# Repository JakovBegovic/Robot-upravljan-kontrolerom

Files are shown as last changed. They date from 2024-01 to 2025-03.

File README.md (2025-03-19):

Razvijeno s kolegama Vinkom Bohnecom, Mateom Zovićem, Antoniom Bernobićem. <br>
Izvorni kod, dokumentacija i video prikaz projekta za kolegij Programiranje ugrađenih sustava. Sadrži kod za 2 mikrokontrolera - odašiljač WiFi signala i primatelj WiFi signala. Projekt razvijen u PlatformIO ekstenziji za Visual Studio Code. Kod je razvijen za Dasduino CONNECTPLUS mikrokontrolere.<br>
Iz projekta dobiveni svi bodovi. Kao posljedica projekta dobivena [pisana preporuka](https://github.com/JakovBegovic/Robot-upravljan-kontrolerom/blob/caef50e12dc3403a5f9ce1389835898fd6788e6c/Pismo%20preporuke%20za%20Jakova%20Begovi%C4%87a.pdf) dr. Borisa Tomaša.
<br><br>
Mapa [3D-modeli](https://github.com/JakovBegovic/Robot-upravljan-kontrolerom/tree/2fcbab7a2e5f61b7f1df8ae97a9870575ed1f150/3D-modeli) sadrži .stl datoteke. One predstavljaju gornji i donji dio kućišta daljinskog upravljača.
<br><br>
Za videozapis koji prikazuje kako robot funkcionira me kontaktirajte.
<br><br>
Shield: [][cc-by-nc-sa]

This work is licensed under a
[Creative Commons Attribution-NonCommercial-ShareAlike 4.0 International License][cc-by-nc-sa].

[][cc-by-nc-sa]

[cc-by-nc-sa]: http://creativecommons.org/licenses/by-nc-sa/4.0/
[cc-by-nc-sa-image]: https://licensebuttons.net/l/by-nc-sa/4.0/88x31.png
[cc-by-nc-sa-shield]: https://img.shields.io/badge/License-CC%20BY--NC--SA%204.0-lightgrey.svg

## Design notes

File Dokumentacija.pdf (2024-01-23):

SVEUČILIŠTE U ZAGREBU

FAKULTET ORGANIZACIJE I INFORMATIKE

V A R A Ž D I N

Vinko Bohnec, Antonio Bernobić,

Mateo Zović, Jakov Begović

Studij: Informacijski i poslovni sustavi

# ROBOT UPRAVLJAN KONTROLEROM

PROJEKT

Mentor/Mentorica:

mag. inf. Lovro Posarić

Varaždin, siječanj 2023.

i

Vinko Bohnec, Antonio Bernobić,

Mateo Zović, Jakov Begović

Izjava o izvornosti

Izjavljujemo da je naš projekt izvorni rezultat našeg rada te da se u izradi istoga nismo

koristili drugim izvorima osim onima koji su u njemu navedeni. Za izradu rada su korištene

etički prikladne i prihvatljive metode i tehnike rada.

ii

Sažetak

Projekt se bavi izradom robota kojim je moguće upravljati preko vlastito izrađenog

kontrolera (daljinskog upravljača). Robot omogućuje razne mogućnosti i funkcionalnosti, od

kojih su neke, upravljanje kretanjem robota, paljenje i gašenje led svjetla u definiranim

intervalima, puštanje raznih zvučnih signala i melodija putem zujalice te automatsko

kočenje. Temelj projekta jesu dvije Dasduino pločice koje međusobno komuniciraju i

razmjenjuju podatke. Jedna od njih služi kao kontroler za slanje naredbi, dok druga

Dasduino pločica obavlja definirane radnje. Projekt ne iziskuje samo trud oko slaganja

robota i spajanja dijelova, već se bazira i na kvalitetnom programskom rješenju. Svaka

Dasduino pločica ima zaseban program koji izvršava svake sekunde. Ovaj projekt

predstavlja savršen spoj mehanike (dijelovi robota), elektronike (elektroničke komponente)

i informatike (programiranja), koji u konačnici tvore robota.

Ključne riječi: robot, daljinsko upravljanje, kretanje, Dasduino pločice, komunikacija

programsko rješenje, mehanika, elektronika, informatika

iii

## Sadržaj

## 1. Uvod

U današnjem svijetu sve više i više je prisutno raznih robota. Svi smo se, već sigurno

bar jednom, susreli s pojmom robota, no što je zapravo robot i kako on djeluje? „Robot je

automatizirani stroj višestruke namjene, koji može obavljati neke zadaće slične ljudskom

djelovanju. S obzirom na stupanj autonomnosti, mogućnosti interakcije s okolinom i

inteligencije, razlikuje se nekoliko skupina (generacija) robota.“ [1] Prvoj skupini pripadaju

programirani roboti, u drugu skupinu spadaju roboti opremljeni nizom senzora, a trećoj skupini

robota pripadaju inteligentni roboti. „Programirani roboti ne koriste povratnu informaciju o

svojem stvarnom stanju i ne mogu korigirati pogrješke vođenja. Roboti druge generacije

opremljeni su nizom senzora, koje koriste za dobivanje povratnih informacija o svojem

stvarnom stanju i stanju okoline. Inteligentni roboti imaju sposobnost učenja, rezoniranja i

donošenja zaključaka.“ [1] S obzirom na brzi razvoj robota, kojem trenutno najviše pridonosi

ubrzani razvoj umjetne inteligencije, nije ni čudo da su danas roboti prisutni u mnogim

djelatnostima. Shodno tome, roboti imaju različite primjene, od industrijskih i kućanskih robota,

pa sve do svemirskih i humanoidnih robota. Iz svega navedenog je na posljetku, i tema našeg

projekta proizašla iz ideje i želje za izradom vlastitog robota. Izrada robota nije jednostavna jer

ona uključuje složeni sustav koji objedinjuje računalnu opremu i komponente te programsku

podršku to jest izvršni program. Upravo robot i njegove komponente predstavljaju pojam

ugrađenog sustava, a njegovim izvršnim programom se ostvaruje ideja programiranja za

ugrađene sustave. Iz tog razloga, robot upravljan vlastoručno izrađenim kontrolerom

predstavlja savršenu temu za stjecanje novih znanja i vještina iz područja ne samo robotike,

već i iz čitavog područja ugrađenih sustava.

## 2. Modeli

Model u tehničkom svijetu predstavlja pojednostavljenu stvarnost. Dakle, prema nekim

predmetima iz stvarnosti moguće je izraditi (najčešće) manju, pojednostavljenu repliku tog

predmeta. Izradom modela se nastoji omogućiti promatranje kompleksnog sustava i njegovih

ključnih dijelova. U ovome slučaju, model robota je prikazan na način da se dijelovi robota prvo

promatraju kao samostalna cjelina, a tek kasnije kao složena cjelina, to jest složeni sustav.

## 2.1. Općenita arhitektura sustava

Osnovna konstrukcija robota sastoji se od postolja robota, četiri kotača, četiri

istosmjerna (DC) motora, te vijaka i matica. Takva konstrukcija tvori temelj za daljnji razvoj

robota. Na osnovnu konstrukciju su nadalje dodani razni elektronički dijelovi potrebni za

ispravno funkcioniranje robota. Ti dijelovi će biti predstavljeni pojedinačno u sljedećim

poglavljima.

Slika 1: Osnovna konstrukcija robota - Dijelovi

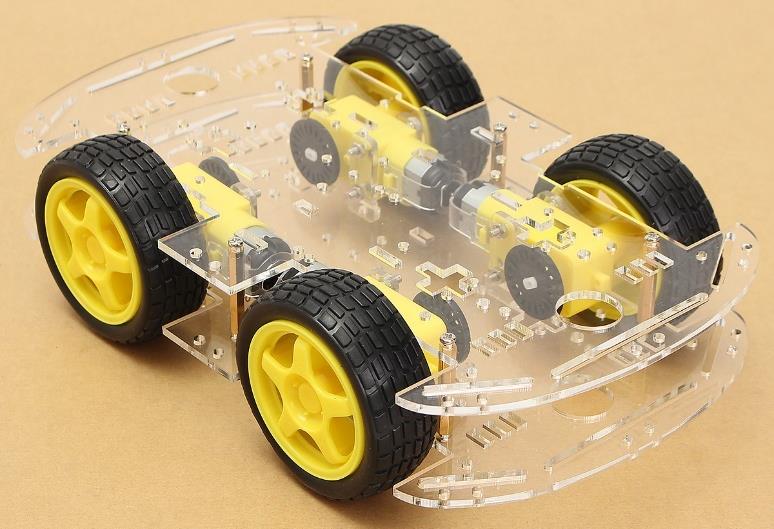
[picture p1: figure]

Slika 2: osnovna konstrukcija robota - Sastavljeno

Slika 1: osnovna konstrukcija robota - Dijelovi

### 2.1.1.Dasduino CONNECTPLUS (ESP32)

Dasduino CONNECTPLUS pločica je elektronička pločica razvijena od hrvatske

kompanije Soldered Electronics. Soldered Electronics nalazi se u Osijeku, a bavi se razvojem,

dizajniranjem te proizvodnjom vlastitih elektroničkih proizvoda. Jedan od njihovih proizvoda

jest Dasduino pločica. Postoje različite vrste pločica Dasduina, koje se razlikuju po čipu koji

koriste i elektroničkoj shemi. U sljedećem dijelu će biti opisana pločica korištena u ovome radu

- Dasduino CONNECTPLUS (ESP32).

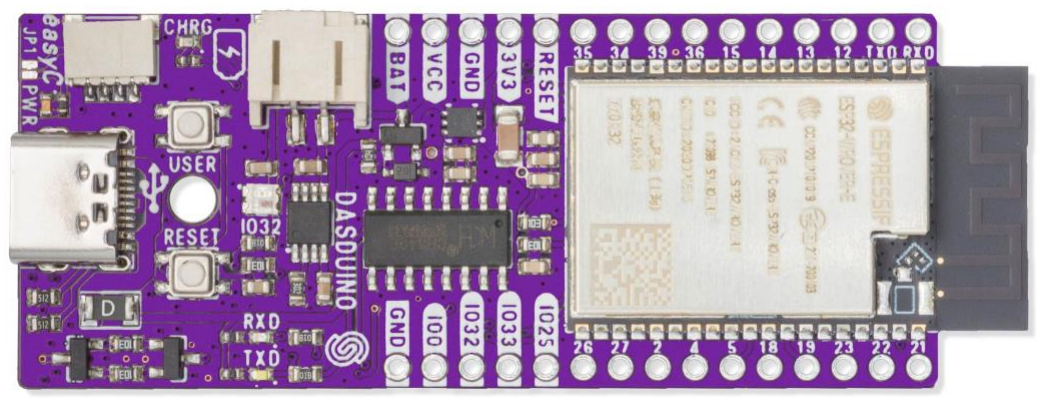
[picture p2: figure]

Dasuino CONNECTPLUS pločica koristi mikročip ESP32-WROVER-E, te koristi napon

rada 3.3V (integrirani 5V regulator). Pločica se sastoji od 30 pinova, od kojih neki rade s

digitalnim signalima, analognim te onih pinova koji imaju mogućnost upravljanja širinom

(duljinom) impulsa (PWM). Na sljedećoj slici [Slika 4] je prikazana Dasduino CONNECTPLUS

pločica skupa sa svojima konekcijama.

Slika 3: Dasduino CONNECT PLUS

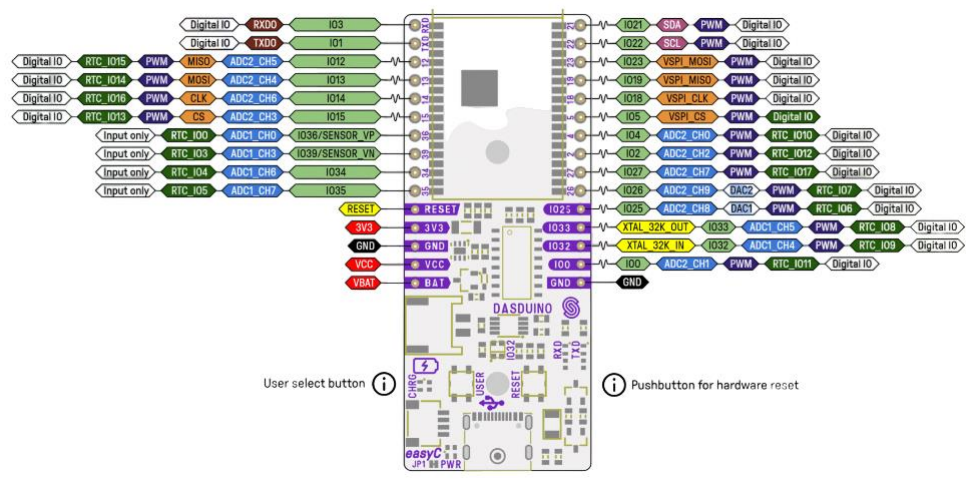
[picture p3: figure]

Na prikazu konekcija se može uočiti da većina pinova sadrži opciju upravljanja širinom

impulsa (PWM – Pulse Width Modulation), a samim time, ti pinovi se mogu koristiti za rad s

analognim signalima. Skoro svi pinovi omogućavaju rad s ulaznim i izlaznim signalima (IO –

Input Output).

### 2.1.2. Modul za upravljanje motorima - L298N DC motor driver

Za upravljanje motorima robota nije dovoljna samo Dasduino pločica, već je potreban i

upravljač motora, koji je u ovom slučaju to L298N DC motor driver. Na taj način se preko

Dasduino pločice šalju naredbe upravljaču motora o promjenama brzine i smjeru vrtnje motora.

Slika 4: Dasduino CONNECTPLUS (ESP32) - Prikaz konekcija

Slika 5: L298N DC motor driver

Promjena brzine vrtnje motora se ostvaruje promjenom ulaznog napona na motorima.

Taj princip rada se zasniva na promjeni širine impulsa (PWM – Pulse Width Modulation) tako

što slanjem duljih impulsa dajemo veću brzinu vrtnje motora, a slanjem manjih odnosno kraćih

impulsa dajemo manju brzinu vrtnje motora, što je vidljivo na sljedećoj slici [Slika 6].

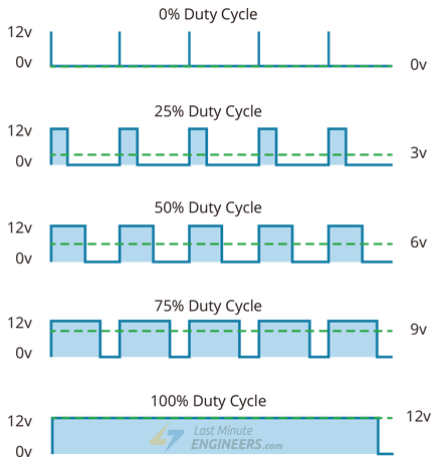
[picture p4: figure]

Promjena smjera vrtnje motora se ostvaruje promjenom polariteta ulaznog napona, a

takav način rada zasnovan je na principu H-Bridge. H označava izgled strujnog kruga u kojem

imamo 4 sklopke od koje su dvije sklopke zatvorene, dok su druge dvije otvorene. Time

mijenjamo polaritet napona na motorima. Bridge, što u prijevodu označava most, isto

predstavlja izgled i način rada strujnog kruga, čiji je princip rada prikazan na sljedećoj slici

[Slika 7].

Slika 6: promjenom širine impulsa dobiva se različiti napon na izlazu

Slika 7: mijenjanje polariteta napona na motorima H-Bridge principom

Kod L298N DC motor drivera L298N predstavlja naziv čipa koji koristi, koji je srce toga

modula. DC (Direct Current) označava da taj modul koristi istosmjernu struju, a motor driver

opisuje funkciju modula – upravljanje motorima. Pomoću L298N DC motor drivera možemo

upravljati dvama istosmjernim motorima istovremeno, koji se napajaju od 5 do 35 V. Njih

spajamo na izlaze 1,2,3 i 4 (OUT1, 2 ,3, i 4). Pomoću ENA i ENB upravljamo brzinama vrtnje

motora, a ulazima 1,2,3 i 4 (IN1, 2, 3, i 4) upravljamo smjerom vrtnje motora. VCC je napajanje,

koje služi za pogon motora, a može biti između 5 i 35 V (preporuča se između 7 i 12 V). GND

označava minus gdje se strujni krug zatvara. Za ispravan rad modula, potrebno je dovesti 5 V

na pin 5V kako bi modul radio.

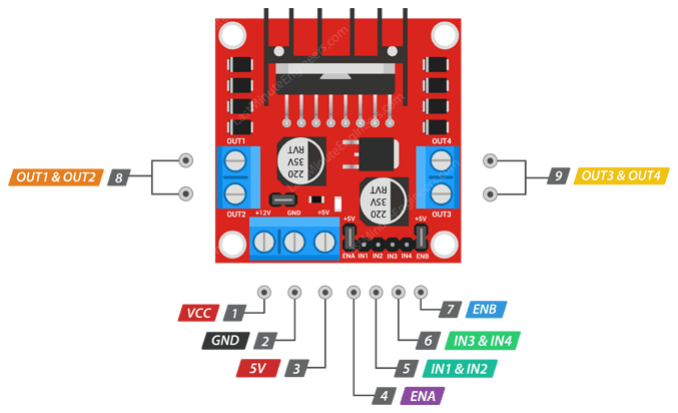
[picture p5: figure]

### 2.1.3. Senzor udaljenosti – HC-SR04 Ultrasonic Sensor

Senzor udaljenosti ili ultrazvučni senzor je senzor za mjerenje udaljenosti pomoću

ultrazvučnih valova. Glava senzora emitira ultrazvučni val koji se odbija od nekog predmeta ili

objekta te se nazad vraća do glave senzora. Ultrazvučni senzor mjeri udaljenost objekta

mjerenjem vremena između emisije i prijema, odnosno između slanja i primanja signala. Za

ispravan rad senzora udaljenosti potrebno je pravilno spojiti četiri pina samog senzora. Vcc pin

služi za napajanje senzora, a najčešće je to 5 V. Trigger pin se koristi za slanje signala, dok

se Echo pin koristi za primanje signala. Ground pin se, kao i obično, spaja na minus to jest

uzemljenje, a služi za zatvaranje strujnog kruga. Izgled senzora udaljenosti i njegovih pinova

prikazan je na sljedećoj slici [Slika 9].

Slika 8: L298N DC motor driver – Prikaz pinova

HC-SR04 ultrazvučni senzor udaljenosti, u teoriji, može izmjeriti udaljenost između 2

cm i 450 cm, dok je praksi ta udaljenost puno manja – od 2 cm do 80 cm. Senzor računa

udaljenost s preciznošću od 3 mm. Za izračun udaljenosti između objekta i senzora koristi se

formula:

L =

1
2

∗ T ∗ C

gdje L predstavlja udaljenost, T vrijeme proteklo između slanja i primanja signala, te C koji

predstavlja brzinu zvuka. Umnožak se množi s

1
2

kako bi se dobila vrijednost udaljenosti za

jedan smjer (a ne za oba). Vrijednost koja se uzima za brzinu zvuka je 330m/s.

Slika 9: HC-SR04 Ultrasonic Sensor - Prikaz pinova

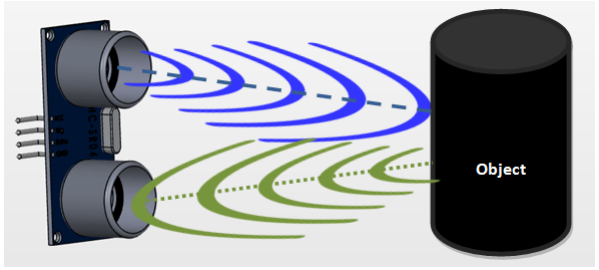
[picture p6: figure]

Slika 10: princip rada ultrazvučnog senzora

### 2.1.4. Zujalica

Zujalice su elektronički elementi predviđeni za generiranje zvuka. Postoje dvije vrste

zujalica – aktivna i pasivna zujalica. Aktivna zujalica ima u sebi ugrađen oscilatorski krug, te ju

je dovoljno spojiti na izvor napajanja i ona će proizvoditi zvuk određene frekvencije. Kod

zujalice bez oscilatorskog kruga, to jest kod pasivne zujalice, potrebno je dovesti oscilirajući

signal kako bi proizvela zvuk. Oscilirajući signal jednostavno je postići jer se programiranjem

može odrediti početak i kraj generiranja zvuka, odnosno tona. Aktivna i pasivna zujalica se

mogu razlikovati tako što aktivna zujalica ima crno dno, dok pasivna ima dno zelene boje.

Njihovo spajanje se izvodi na način da se + (plus) zujalice spaja na neki od digitalnih pinova

na Dasduino pločici, dok se – (minus) zujalice spaja na GND.

### 2.1.5. Svjetleće diode

Naziv LED dolazi iz engleskog jezika i kratica je za Light Emitting Diode, što bi u

prijevodu značilo dioda koja emitira svjetlost. Hrvatski naziv je svjetleća dioda, međutim u

praksi se najčešće koristi izraz LE-dioda. LE-dioda ima dvije nožice od kojih je jedna duža, dok

je druga kraća. Duža nožica se zove anoda i spaja se na + (plus), a kraća nožica, to jest

katoda, spaja se na – (minus). Osim po duljini nožice, anodu je moguće prepoznati jer je u

kućištu presjek (zarez) dviju nožica bliži anodi, odnosno površina katode u kućištu je veća od

površine anode. Kako bi LE-dioda zasvijetlila potrebno ju je priključiti na napon od oko 2 V.

Dakle, anoda se spaja na digitalni pin, dok se katoda spaja na GND. Međutim, svaki digitalni

pin daje 5 V, zbog čega je potrebno dodati otpornik od 330 Ω u strujni krug kako LE-dioda ne

bi pregorjela.

Slika 11: zujalice - Aktivna zujalica (lijevo) i Pasivna zujalica (desno)

Slika 12: svjetleća dioda - Prepoznavanje anode i katode

### 2.1.6. Maska odašiljača

U svrhu uljepšavanja i unaprjeđenja našeg proizvoda, koristili smo 3D printer kako bi

isprintali masku za odašiljač radio signala. U svrhu toga koristili smo alat Fusion 360.

Na slici gore moguće je vidjeti donji dio maske. On sadrži držač za bateriju i logo „GoranTM“. Držač za bateriju napravljen je za bateriju koja će napajati odašiljač. Nakon

printanja otvor je bio pre uzak te smo stoga trebali koristiti brusilicu kako bi ga proširili za oko

pola milimetra. Nepreciznost 3D printera dovela je do užeg otvora nego očekivano.

Slika 13: donji dio maske

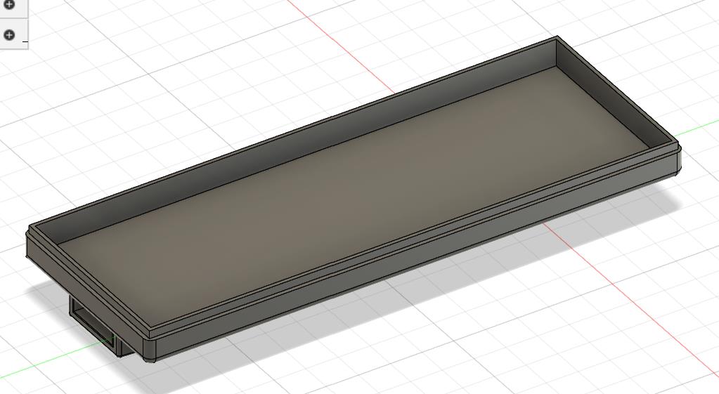
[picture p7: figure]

Slika 14: ptičja perspektiva na donji dio maske

Uz to, ovaj donji dio poklopca ima uvlaku na samom rubu, kao što je prikazano na slici

gore. Svrha tome je da se spoji sa gornjim dijelom maske bez korištenja ljepila. Na taj način

se baterija može izmijeniti nakon što se potroši. Tolerancija između uvlake gornjeg i donjeg

dijela maske je ukupno 0,1 mm.

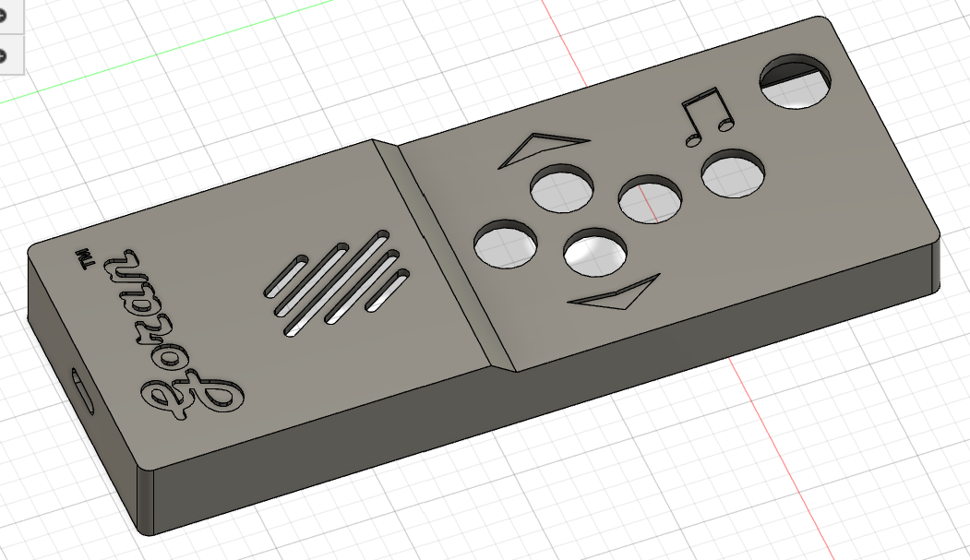
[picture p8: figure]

Gornji dio maske sadrži prostor za 5 gumba, rupu za zujalicu, uzdužene rupe za

hlađenje mikroupravljača, rupu za USB-C konektor, rupu za spajanje baterije na

mikroupravljač, sugestivne reljefe vezane uz funkcionalnosti gumbova i logo projekta.

Gumbovi na odašiljaču imaju toleranciju od oko 2 mm od rupa koje su za njih izrađene.

Slika 15: mravlja perspektiva na gornji dio maske

Slika 16: ptičja perspektiva na gornji dio maske

## 2.2. Složena arhitektura sustava

Elektroničke komponente navedene u prošlim poglavljima, ovdje čine jednu zajedničku

cjelinu, odnosno predstavljaju složeni sustav robota. Kako točno robot funkcionira, razmjenjuje

podatke i prima naredbe biti će razrađeno u ostalim poglavljima, dok je cilj ovog poglavlja

vizualno prikazati izgled robota. Shema spajanja će također biti predstavljena kasnije.

Slijedeće slike [Slika 17], [Slika 18] služe za lakše razumijevanje poglavlja koja slijede, pritom

pružajući čitatelju jasnu sliku o predmetu promatranja.

Slika 17: Prikaz složenog robota

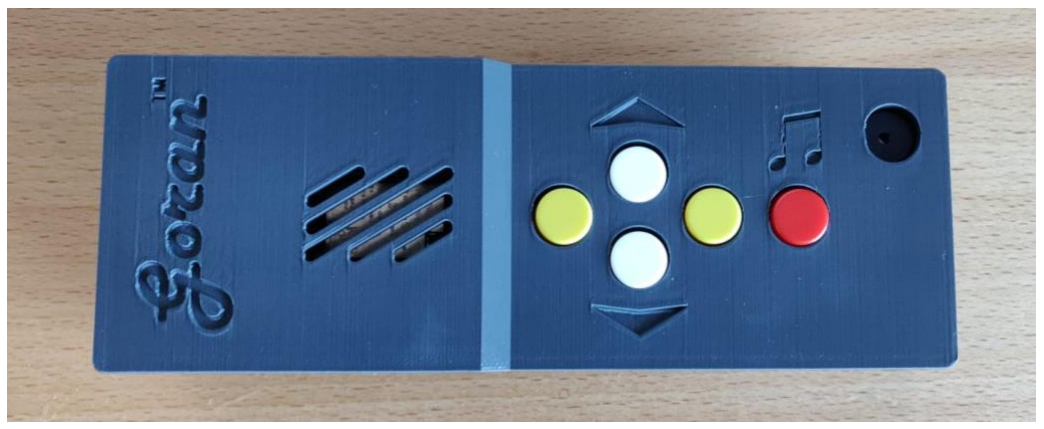
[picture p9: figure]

Slika 18: Prikaz daljinskog kontrolera (odašiljača)

## 2.3. Komunikacijski dijagrami

Prema [5] komunikacijski dijagram je tip UML dijagrama koji prikazuje interakciju

između objekata, dijelova ili podsistema. Isključujući temporalnu komponentu, on daje iste

informacije kao dijagram slijeda.

U sljedećih par dijagrama odnosit ću ne na gumbove „gore“, „dolje“, „lijevo“, „desno“ i

„muzika“. To su 4 gumba nađena na odašiljaču. Kada se on usmjeri tako da su gumbovi bliži

desnoj ruci, tada je vidljiv njihov točan poredak. Gumb „muzika“ je prepoznatljiv po silueti dvaju

povezanih nota na kućištu odašiljača.

### 2.3.1. Korisnik ne pritišće niti jedan gumb

Na slici gore možete vidjeti kako komponente ovog robota međusobno komuniciraju u

slučaju da korisnik ne pritišće niti jedan gumb. Mikrokontroler RF auta, kao i mikrokontroler

odašiljača su tipa ESP32. To znači da sadrže dvije procesorske jedinice – CPU0 i CPU1. [6]

CPU0 je zaslužan za procesiranje mrežnih zadataka, kao što je komuniciranje putem WiFi ili

Bluetooth tehnologije. CPU1 je zaslužan za izvršavanje ostalog koda, kao što je upravljanje

motorima i paljenje i gašenje LED-ica.

Poruka 2 predstavlja slanje paketa koji sadrži naredbu sa odašiljača na robot auto. U

slučaju kada korisnik ne pritišće niti jedan gumb naredba koja se šalje je cijeli broj 0. Taj se

Slika 19: dijagram komunikacije kada korisnik ne pritišće niti jedan gumb paket šalje sa CPU0 na odašiljaču na CPU0 na primatelju. Poruka 3. predstavlja dodjeljivanje

procesorskog vremena objektu tipa MusicPlayer.

Poruka 4 i 5 predstavlja prijepis vrijednosti primljene naredbe u varijablu dijeljenu

između CPU0 i CPU1 kod robot auta. OnDataRecv() je zapravo funkcija pozvana nakon

primanja paketa.

Poruke 6, 7, 8, 9 i 10 se odnose na dodjeljivanje objektima ultrasonicControlForward,

ultrasonicControlForward, rightBlinker, leftBlinker i backwardsBuzzer procesorsko vrijeme.

Svrha toga je održavanje pravilnog vremena treptanja LED-ica, pravog vremena i duljine

sviranja nota na zujalici, provjeravanje udaljenosti prednjeg i stražnjeg branika robot auta od

drugih objekata.

U slučaju kada se niti jedan gumb ne pritišće naredba kojom se upravljaju motori je

Stop(). Ona se šalje motorima koji upravljaju kotačima robota. To je vidljivo putem poruke 11.

Poruke 12 i 13 se odnose na gašenje LED-ica. Naime, one bi trebale biti upaljene samo

kada robot auto skreće lijevo ili desno.

Poruka 14 daje informaciju je li upaljena zujalica koja signalizira vožnju u natrag. Ako

je, treba ju ugasiti. To se radi pomoću naredbe 15.

### 2.3.2. Korisnik pritišće gumb gore

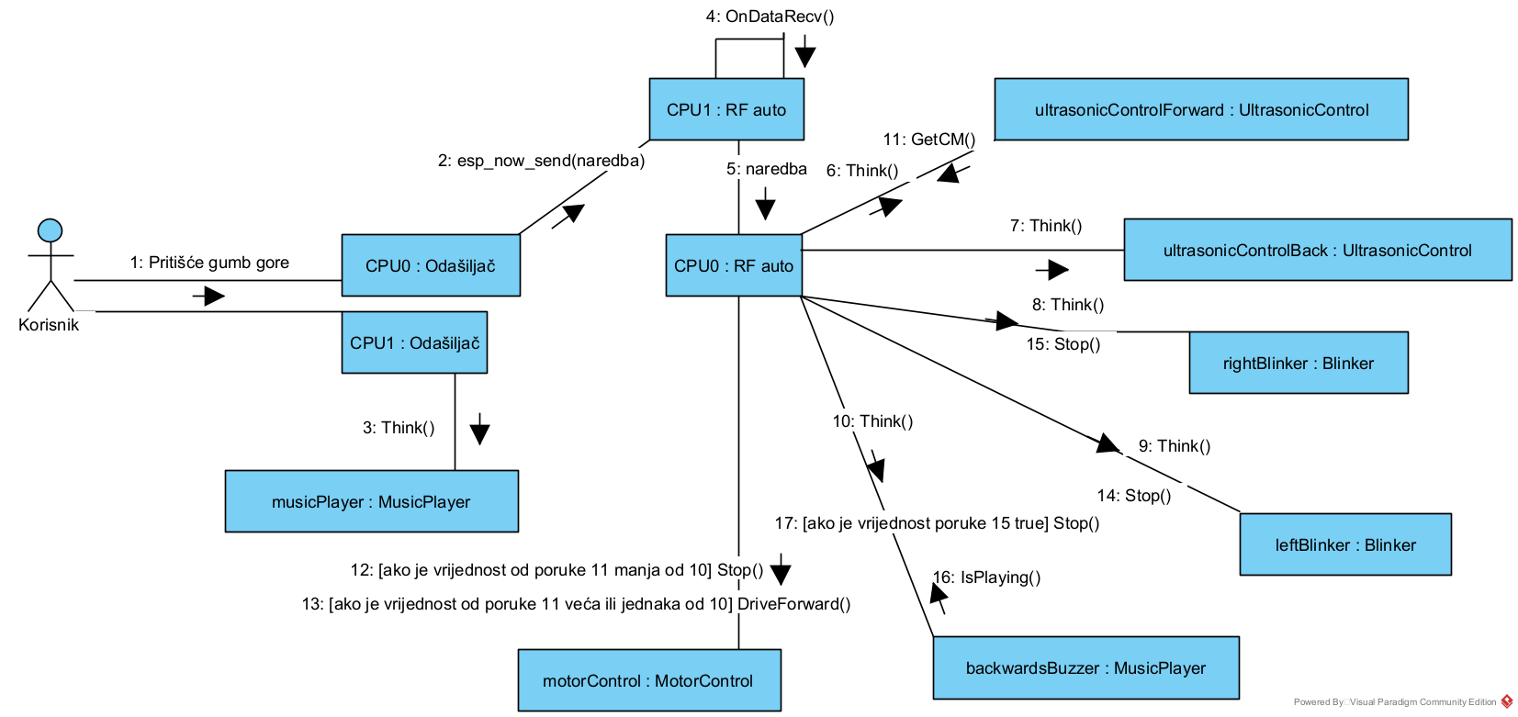
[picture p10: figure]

Slika 20: dijagram komunikacije kada korisnik pritišće gumb gore

Na slici gore možete vidjeti kako komponente ovog robota međusobno komuniciraju u

slučaju da korisnik pritišće gumb gore. Poruke 1, 2, 3, 4, 5, 6, 7, 8, 9, 10 su iste kao i na

prošlom dijagramu.

Svrha poruke 11 je prikupljanje informacije koliko je prednji branik robot auta udaljen

od sljedećeg objekta. Ta vrijednost je zatim korištena u porukama 12 i 13 gdje se njihova

pojava bazira na toj vrijednosti. Vrijednost 10 predstavlja 1 centimetara od sljedećeg objekta.

To je udaljenost na kojoj bi robot auto trebao blokirati vožnju dalje.

Poruke 14 i 15 identične su porukama 12 i 13 na prošlom dijagramu. Poruke 16 i 17

identične su porukama 14 i 15 na prošlom dijagramu.

### 2.3.3. Korisnik pritišće gumb dolje

Na slici gore možete vidjeti kako komponente ovog robota međusobno komuniciraju u

slučaju da korisnik pritišće gumb dolje. Poruke 1, 2, 3, 4, 5, 6, 7, 8, 9, 10 su iste kao i na

prošlom dijagramu.

Svrha poruke 11 je prikupljanje informacije koliko je prednji branik robot auta udaljen

od sljedećeg objekta. Ta vrijednost je zatim korištena u porukama 12 i 13 gdje se njihova

pojava bazira na toj vrijednosti. Vrijednost 10 predstavlja 1 centimetara od sljedećeg objekta.

To je udaljenost na kojoj bi robot auto trebao blokirati vožnju dalje.

Poruke 14 i 15 identične su porukama 12 i 13 na prošlom dijagramu. Poruke 16 i 17

identične su porukama 14 i 15 na prošlom dijagramu.

Slika 21: dijagram komunikacije kada korisnik pritišće gumb dolje

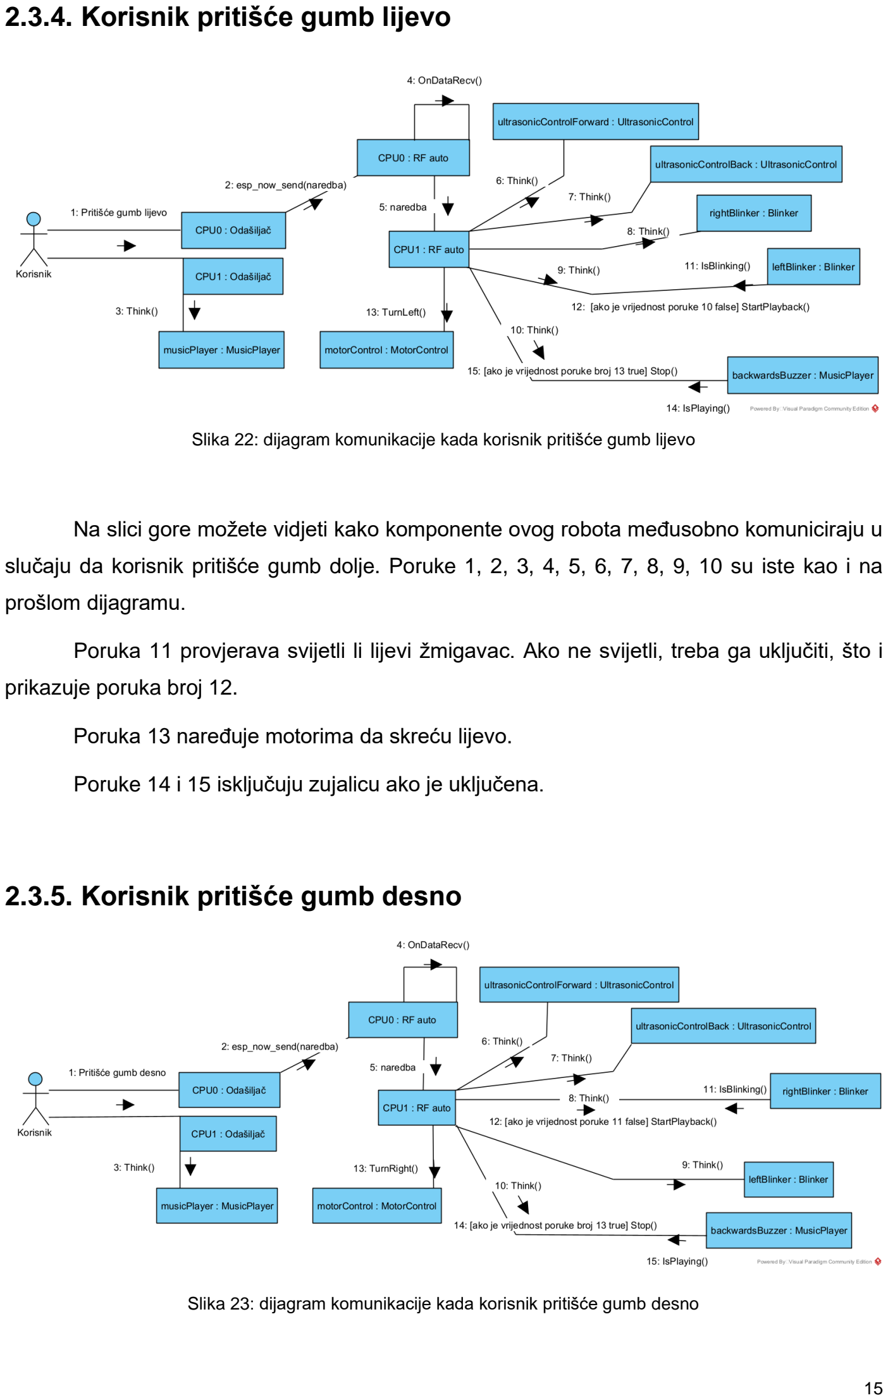
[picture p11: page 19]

### 2.3.4. Korisnik pritišće gumb lijevo

Na slici gore možete vidjeti kako komponente ovog robota međusobno komuniciraju u

slučaju da korisnik pritišće gumb dolje. Poruke 1, 2, 3, 4, 5, 6, 7, 8, 9, 10 su iste kao i na

prošlom dijagramu.

Poruka 11 provjerava svijetli li lijevi žmigavac. Ako ne svijetli, treba ga uključiti, što i

prikazuje poruka broj 12.

Poruka 13 naređuje motorima da skreću lijevo.

Poruke 14 i 15 isključuju zujalicu ako je uključena.

### 2.3.5. Korisnik pritišće gumb desno

Slika 23: dijagram komunikacije kada korisnik pritišće gumb desno

Slika 22: dijagram komunikacije kada korisnik pritišće gumb lijevo

Na slici gore možete vidjeti kako komponente ovog robota međusobno komuniciraju u

slučaju da korisnik pritišće gumb desno. Poruke 1, 2, 3, 4, 5, 6, 7, 8, 9, 10 su iste kao i na

prošlom dijagramu.

Poruka 11 provjerava svijetli li desni žmigavac. Ako ne svijetli, treba ga uključiti, što i

prikazuje poruka broj 12.

Poruka 13 naređuje motorima da skreću desno.

Poruke 14 i 15 isključuju zujalicu ako je uključena.

### 2.3.6. Korisnik pritisne gumb muzika

Na slici gore možete vidjeti kako komponente ovog robota međusobno komuniciraju u

slučaju da korisnik pritisne gumb muzika. Nakon pritiska gumba se pozove prekid u obliku

funkcije musicButtonInterrupt(). Svrha tog prekida je postavljanje zastavice za prijelaz na

sljedeću pjesmu. U sebi ima sadržan tzv. switch debouncing sa odgodom detekcije od 200

milisekundi. Korak 3 izvršava se neovisno o tom pritisku – u svakom slučaju. Zbog pritiska

gumba muzika aktivira se korak 4. Tada se objektu musicPlayer pošalje naredba

StartPlayback() koja završi sa izvađanjem trenutne i krene sa izvađanjem sljedeće pjesme.

Poruka broj 5 je pozivanje metode Think() unutar same klase. Svrha toga je

dodjeljivanje procesorskog vremena toj klasi.

Slika 24: dijagram kada korisnik pritišće gumb muzika

## 2.4. Dijagram aktivnosti

Prema [7] dijagrami aktivnosti opisuju kako su aktivnosti koordinirane. To prikazuje na

različitim razinama apstrakcije. Kako bi izgradili model aktivnosti koristili smo notaciju BPMN.

Ona pruža puno više mogućnosti u smislu definiranja vrste prekida, vrste događaja, vrste

grananja i slično.

Cijeli dijagram je podijeljen na 3 staze: stazu korisnik, stazu upravljača-odašiljača i

stazu prijemnika-robota.

### 2.4.1. Staza korisnika

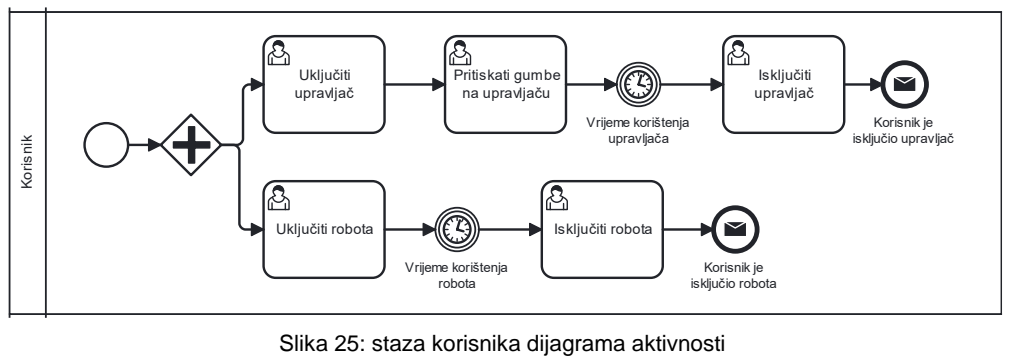
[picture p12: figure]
Korisnik; Uključiti robota; Uključiti upravljač; Pritiskati gumbe na upravljaču; Isključiti upravljač; Isključiti robota; Vrijeme korištenja robota; Korisnik je isključio robota; Korisnik je isključio upravljač; Vrijeme korištenja upravljača

Aktivnosti korisnika se dijele na dva slijeda – slijed uključivanja upravljača i slijed

uključivanja robota. Nakon što korisnik izvede aktivnost uključivanja robota on njime upravlja.

Nakon što je gotov isključuje upravljač. To šalje poruku u stazu upravljača.

Nakon što prođe neko vrijeme kroz koje korisnik koristi robota on ga isključuje i šalje

se poruka stazi robota.

Slika 25: staza korisnika dijagrama aktivnosti

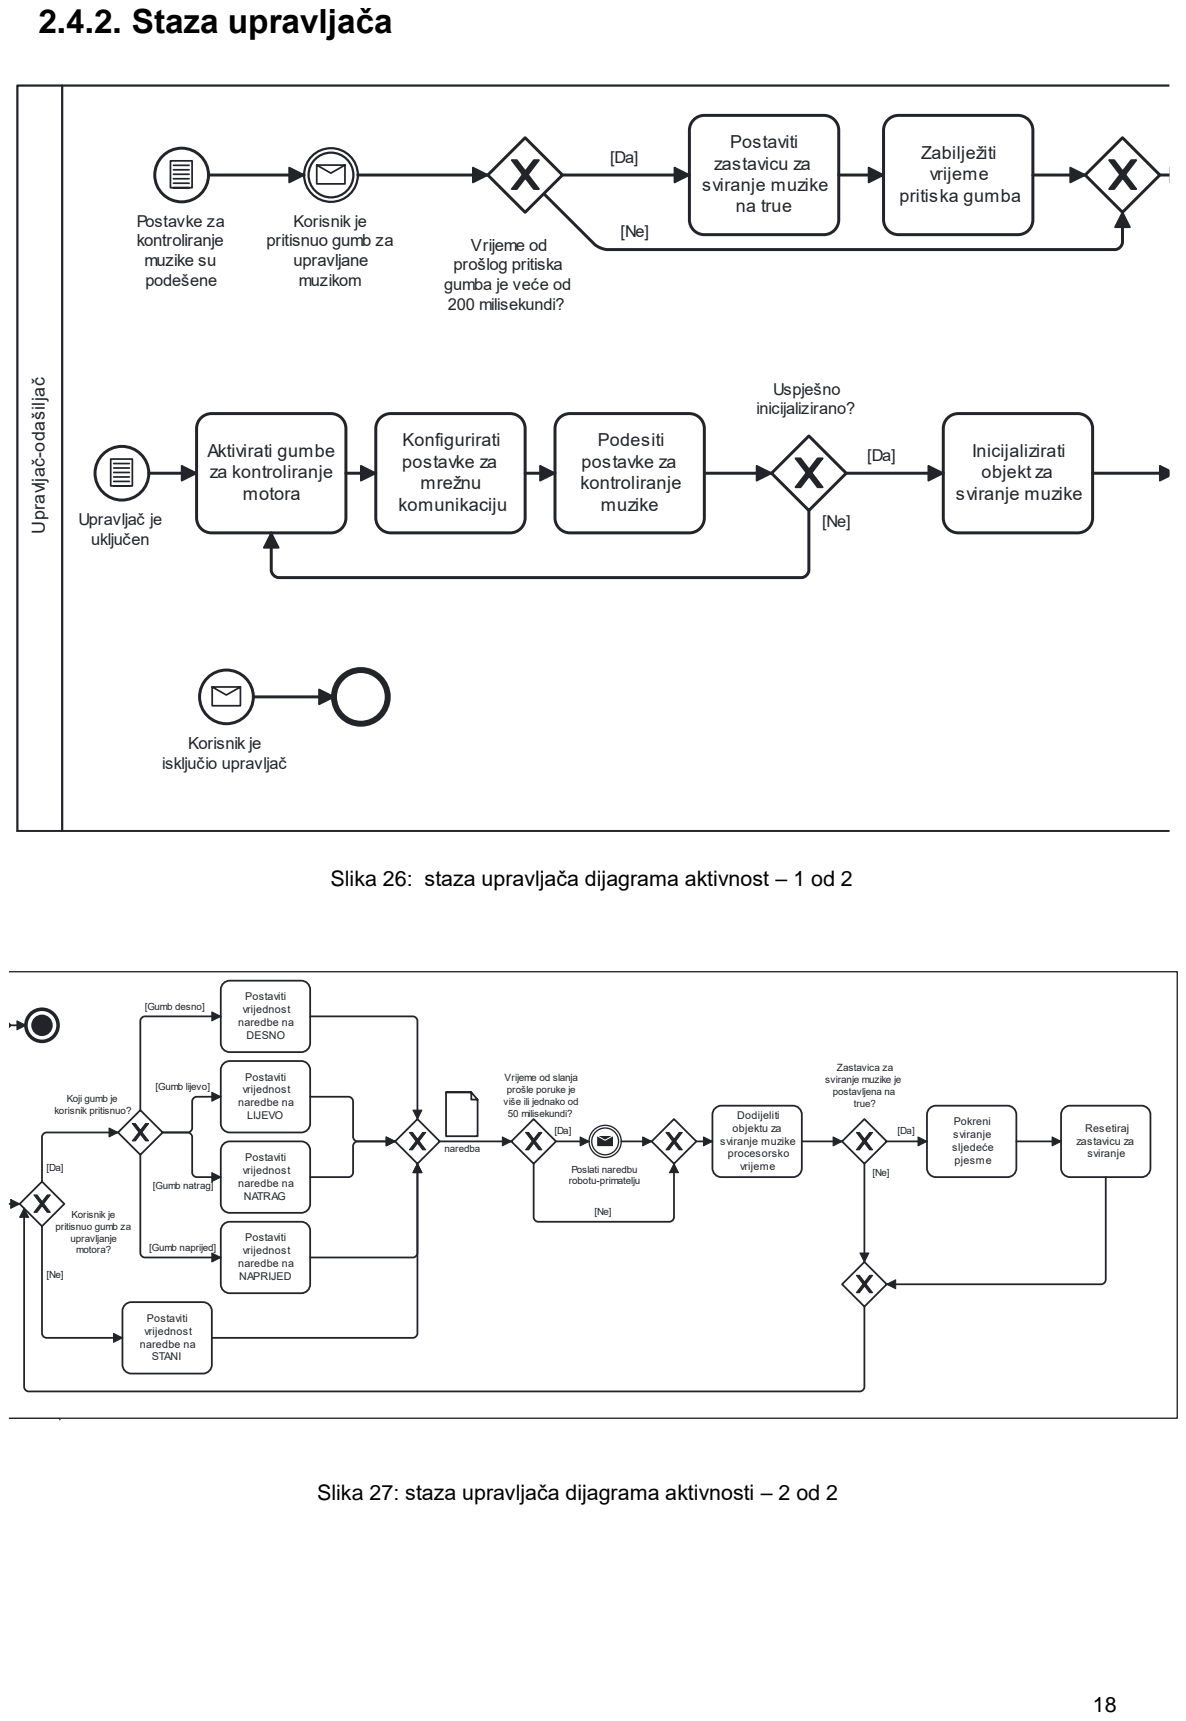
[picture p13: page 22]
2.4.2. Staza upravljača; Upravljač odašiljač; Aktivirati gumbe za kontroliranje motora; Konfigurirati postavke za mrežnu komunikaciju; Podesiti postavke za kontroliranje muzike; Inicijalizirati objekt za sviranje muzike; Postaviti zastavicu za sviranje muzike na true; Zabilježiti vrijeme pritiska gumba; Upravljač je uključen; Uspješno inicijalizirano?; Korisnik je isključio upravljač; Postavke za kontroliranje muzike su podešene; Postaviti vrijednost naredbe na STANI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

Korisnik je
pritisnuo gumb za
upravljane
muzikom

Vrijeme od
prošlog pritiska
gumba je veće od
200 milisekundi?

Slika 26: staza upravljača dijagrama aktivnost – 1 od 2

Vrijeme od slanja
prošle poruke je
više ili jednako od
50 milisekundi?

Zastavica za
sviranje muzike je
postavljena na
true?

Koji gumb je
korisnik pritisnuo?

upravljanje
motora?

Slika 27: staza upravljača dijagrama aktivnosti – 2 od 2

Slike 26 i 27 prikazuju stazu upravljača. Početak izvođenja slijeda su 3 uvjeta: uvjet za

uključivanjem upravljača, uvjet za podešavanjem postavkama muzike i uvjet za isključenjem

upravljača. Ovaj dijagram slijeda prati izvorni kod koji izgrađuje funkcionalnosti upravljača.

Zbog toga postoji duga povratna veza u srednjem slijedu upravljača – aktivnosti unutar te

povratne veze se nalaze u loop() funkciji. Svako ekskluzivno grananje sa da/ne rezultatima

predstavlja if grananje. Grananje provjere koji je gumb pritisnut predstavlja if else slijed

grananja.

Gornji slijed se izvršava svaki put kada korisnik pritisne gumb za upravljanje muzikom

ako su postavke za kontroliranje podešene. Terminirajući događaj terminira samo taj slijed, a

ne i izvođenje ostalih sljedova. S druge strane, kada se isključi upravljač, svi sljedovi se

isključuju.

Događaj slanja naredbe na slici 27 ilustrira mrežnu komunikaciju između upravljača-

odašiljača i robota-primatelja poruka.

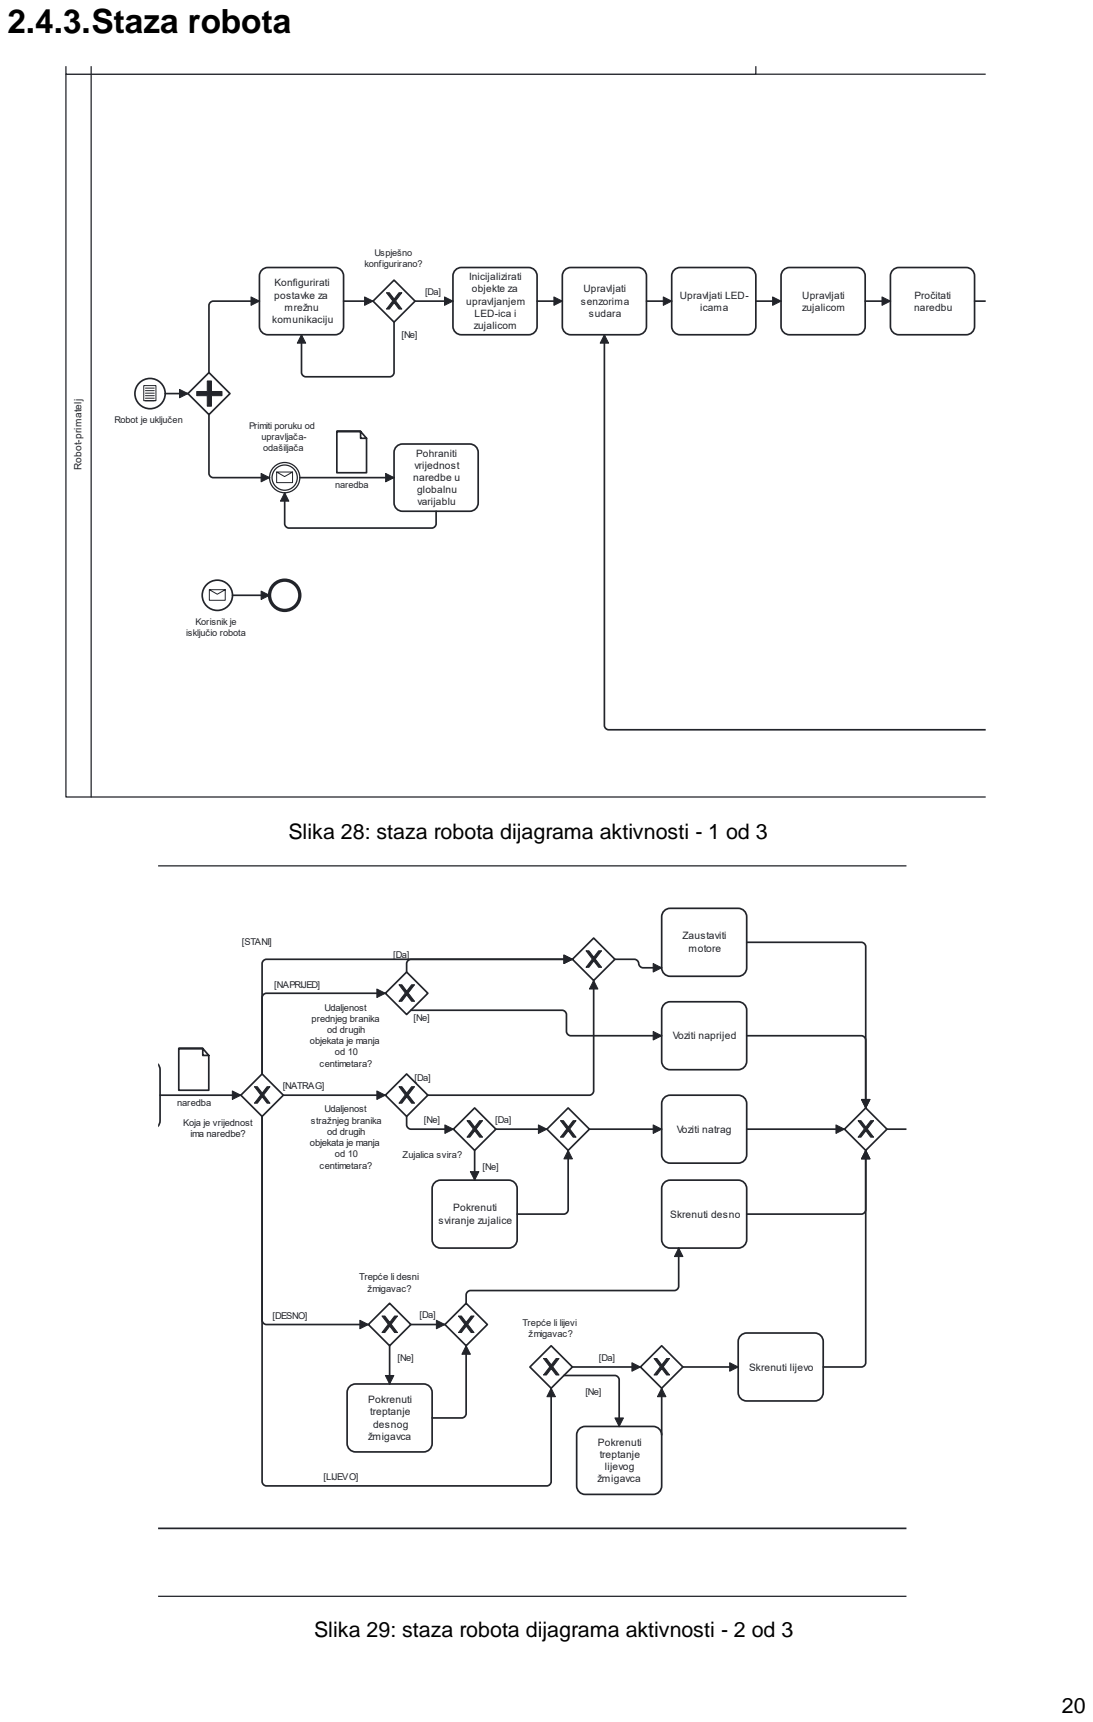
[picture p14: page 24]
2.4.3.Staza robota; Robot primatelj; Konfigurirati postavke za mrežnu komunikaciju; Inicijalizirati objekte za upravljanjem LED ica i zujalicom; Upravljati senzorima sudara; Upravljati LED icama; Upravljati zujalicom; Pohraniti vrijednost naredbe u globalnu varijablu; Pročitati naredbu; Uspješno konfigurirano?; Korisnik je isključio robota; naredba; Zaustaviti motore; Voziti naprijed; Pokrenuti sviranje zujalice; Voziti natrag; Pokrenuti treptanje desnog žmigavca; Skrenuti desno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

Robot je uključen

Primiti poruku od
upravljača
odašiljača

Slika 28: staza robota dijagrama aktivnosti - 1 od 3

Udaljenost
prednjeg branika
od drugih
objekata je manja

stražnjeg branika

Koja je vrijednost
ima naredbe?

Trepće li desni
žmigavac?

Trepće li lijevi

Slika 29: staza robota dijagrama aktivnosti - 2 od 3

Kada se robot uključi krene se izvršavati jedan slijed aktivnosti. Drugi slijed se krene

izvršavati kada korisnik isključi robota. Slijed nakon uključivanja robota podrazumijeva

izvršavanje 2 paralelna slijeda: 1 koji predstavlja izvođenje setup() i loop() funkcija na CPU1

jezgri ESP32 mikrokontrolera i 1 koji predstavlja izvršavanje ESP NOW mrežnog protokola na

CPU0 jezgri. Događaj primanja poruke od upravljača sadrži poruku naredbe koja se šalje. U

slučaju gašenja robota terminiraju se svi sljedovi na stazi.

Ponovno, postoji dugačka povratna veza jer aktivnosti u njoj predstavljaju izvršavanje

loop() funkcije. Ekskluzivno grananje koje provjerava vrijednost naredbe predstavlja switch

ključnu riječ u kodu. Ponovno, svako ekskluzivno grananje sa da/ne rezultatima predstavlja if

grananje.

Slika 30: staza robota dijagrama aktivnosti – 3 od 3

Zaustaviti
motore

Voziti naprijed

Voziti natrag

Skrenuti desno

Skrenuti lijevo

## 2.5. Shema ili dijagram spajanja

U nastavku su prikazani dijagrami spajanja odašiljača i robota. Iz prikazanog je vidljivo

da spajanje odašiljača nije kompleksno. Na pinovima 12-15 su spojeni gumbovi koji određuju

kratanje robota, odnosno signal koji odašiljač šalje. Na pin 23 je spojen gumb koji kontrolira

sviranje, dok je zujalica spojena na pin 16.

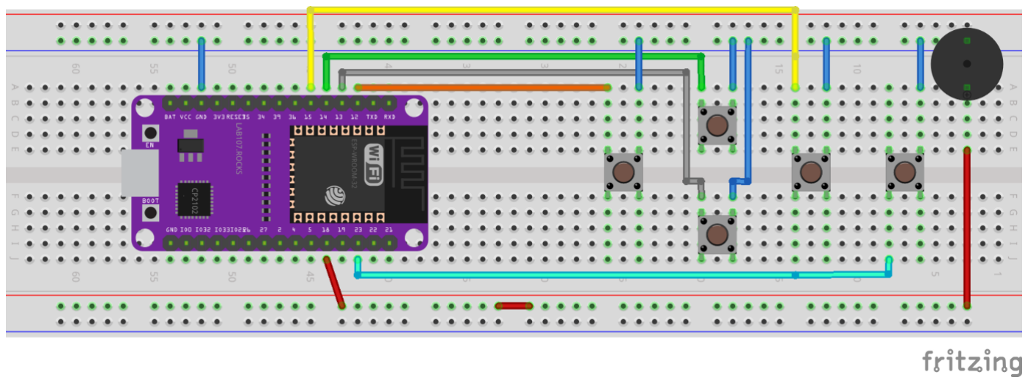
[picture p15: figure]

S druge strane shema robota je nešto kompleksnija pa će se opisati u dijelovima. Kao

prvi dio treba navesti napajanje same pločice koje se vrši na način da se bateriju od 9V spoji

na DC adapter koji napon spušta na 5V s kojima pločica i ostali senzori mogu sigurno raditi.

Izlaz adaptera je spojen na breadboard na dijelu za napajanje koji se proteže duž cijelog

breadborda. Pločica se spaja na spomenuto napajanje putem Vcc pina.

Drugi dio robota su senzori udaljenosti koji su spojeni na napajanje, Echo pinovi su

spojeni na pinove 14 i 15, dok su Trig pinovi spojeni na pinove 4 i 5 koji pružaju opciju

analognog inputa koja je potrebna.

Žmigavci robota, odnosno LED diode su spojene na uzemljenje dok su anode spojene

preko otpornika na pinove 12 i 13. A zujalica je spojena na uzemljenje i na pin 18.

Na kraju su ostali motor driveri koji su spojeni na način da se kontroliraju istim pinovima.

Svaki motor driver je postavljen na način da upravlja jednim lijevim i jednim desnim motorom,

tako da se motor driveri cijelo vrijeme ponašaju jednako. Oni rade na način da imaju vlastito

napajanje spojeno na bateriju od 9V, ulazi za upravljanje su spojeni na pinove 19, 21, 22 i 23

pločice te paralelno na ulaze za upravljanje drugog motor drivera, a izlazi kojih ima 4 spojeni

su u parovima za svaki od 2 motora. ENA i ENB pinovi koji služe za određivanje brzine vrtnje

Slika 31: shema spajanja odašiljača motora su kratko spojeni tako da se motori cijel vrijeme vrte maksimalnom brzinom. Kako bi

pločica mogla upravljati motor driverima potrebno im je spojiti uzemljenje. Na taj način pločica

samo upravlja motor driverima koji koriste vlastito napajanje za pokretanje motora.

Slika 32: shema spajanja robota

## 3. Izvršni program robota

Nakon spajanja robota, potrebno je napisati program po kojemu će robot raditi.

Program je pisan pomoću alata Visual Studio Code, u programskom okruženju PlatformIO IDE

i potom je učitan u Dasduino CONNECTPLUS pločicu preko USB kabla. Na sljedećim

stranicama prikazani su dijelovi programa skupa s njihovim objašnjenjem.

Izvršni kod je podijeljen na dva programa: “Robot-Primatelj” i “Upravljač-Odašiljač”.

Robot-Primatelj upravlja robotom i njihovim komponentama a Upravljač-Odašiljač a drugi

program obrađuje slanje ulaza robotu i sviranje muzike.

## 3.1. Klase

Naše rješenje mora pratiti i upravljati više uređajima i funkcijama istovremeno, kako bi

nam taj posao bio lakše pratiti, izradili smo par klasa koje upravljaju pojedinoj vrsti uređaja.

CBlinker i CMusicPlayer rade na sličnom principu, samo da jedan upravlja LED-icama

a drugi Buzzer-om, tako da ćemo objasniti samo jedan pa onda istaknuti razlike kada potrebno.

Klase se sastoje od 5 metoda:

- Init – Poziva se na početku programa i inicijalizira klasu, postavlja koji PIN se koristi

za funkcije klase te istog postavlja na ispravni način rada

- StartPlayback – Glavna metoda korisničke strane, kao ulaz uzima polje koje

predstavlja uzorak koji će se reproducirati, duljina polja, brzinu sviranja i zastavicu

da | li | će | se | uzorak | ponovno | pokrenuti | ili | ne

Metoda sprema postavke i započinje reprodukciju

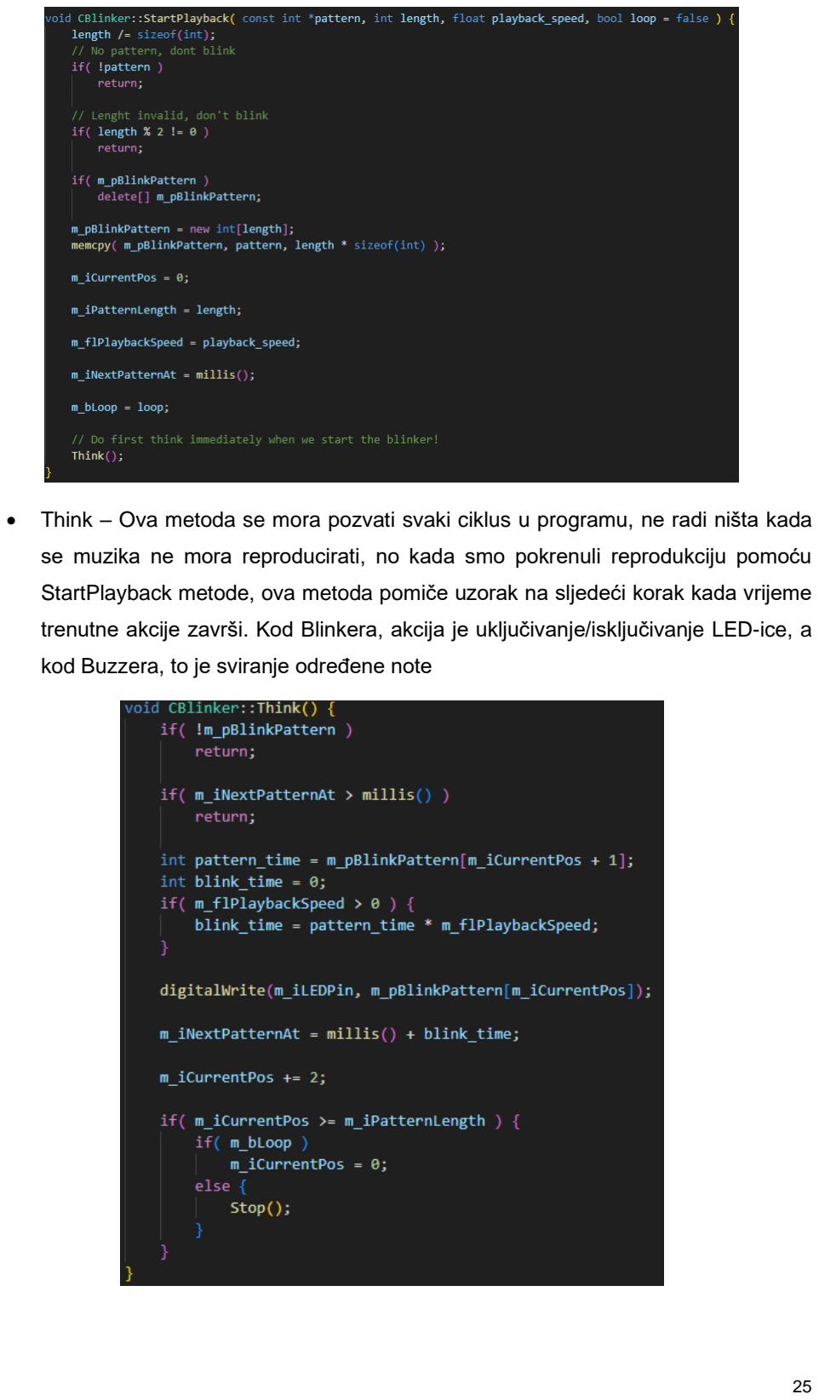
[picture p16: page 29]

- Think – Ova metoda se mora pozvati svaki ciklus u programu, ne radi ništa kada

se muzika ne mora reproducirati, no kada smo pokrenuli reprodukciju pomoću

StartPlayback metode, ova metoda pomiče uzorak na sljedeći korak kada vrijeme

trenutne akcije završi. Kod Blinkera, akcija je uključivanje/isključivanje LED-ice, a

kod Buzzera, to je sviranje određene note

- Stop – Ova metoda trajno zaustavlja reprodukciju, automatski se poziva ako je

petljanje isključeno, u slučaju da nije, ova metoda se treba ručno pozvati kada

želimo da se reprodukcija zaustavi

- IsBlinking/IsPlaying – Ova metoda vrača true ako je trenutna reprodukcija aktivna,

a false ako nije, što znamo ako je postavljen uzorak

Glavne razlike između CBlinker i CMusicPlayer klasa je način izračuna vremena

između koraka i signal koji se šalje na pin. CBlinker koristi milisekunde i HIGH/LOW signal, a

CMusicPlayer koristi bpm i muzičku notaciju za određivanje vremena svakog koraka, i signal

koji šalje je frekvencija Buzzer-a, koja predstavlja notu.

Izračun vremena za muziku, frekvencija nota i pjesme su preuzete s github projekta otvorenog

koda [10].

Ultrazvučni senzor treba obavezno barem 10 milisekundi skenirati prije svakog

učitavanja, a pošto mi trebamo jako često ažurirati udaljenost radi kretanja robota, moramo

imati način da to činimo konstantno i konzistentno, što radimo pomoću CUltrasonicControl

klase.

Klasa radi na sličnom principu kao CBlinker i CMusicPlayer gdje imamo Think metodu koja se

odvija svaki ciklus.

- Konstruktor – Postavlja pinove ultrazvučnog senzora i početne postavke kao što su

trenutačna duljina i trenutačna akcija

- | Think | – | Glavna | metoda, | odvija | se | svaki | ciklus

Kada je akcija postavljena na “SENDING” tj. slanje, pišemo na ultrazvučni senzor

kako bi slao zvučne valove i učitavao udaljenost, ova akcija traje 10 milisekundi,

nakon | kojih | se | prebacimo | na | akciju | “MEASURING”

Kada je akcija postavljena na “MEASURING”, postavimo Ultrazvučni senzor na

“LOW”, te nakon toga učitamo udaljenost koju je izmjerio i spremimo ga u varijablu

m_dLenght, ova akcija traje samo jedan ciklus, te se odmah prebaci nazad na

“SENDING” u sljedećem ciklusu

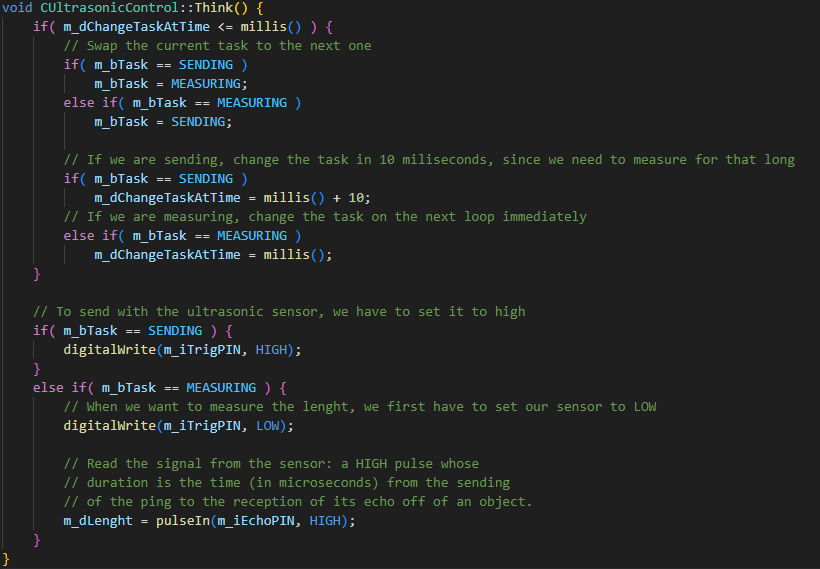
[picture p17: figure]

- GetCM – Ova metoda nam vraća zadnju izmjerenu udaljenost pretvorenu u

centimetre

Zadnja klasa koju koristimo je CMotorControl koja služi za kretanje kotača.

- Konstruktor – Uzima 4 pinova koja predstavljaju kotače
- MotorSetup – Uključuje ispravni pin mode i postavlja pinove na početno stanje

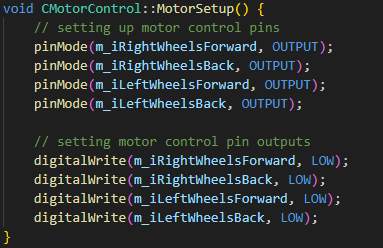
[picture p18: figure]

- DriveForward – Postavlja kretanje kotača prema naprijed
- DriveBackward – Postavlja kretanje kotača prema iza
- TurnLeft – Postavlja desne kotače prema naprijed i lijeve prema nazad kako bi se

okretali prema lijevo

- TurnRight – Postavlja desne kotače prema nazad i lijeve prema naprijed kako bi se

okretali prema desno

- Stop – Zaustavlja sve kotače

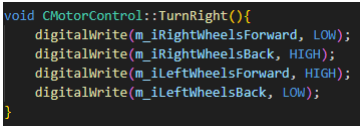
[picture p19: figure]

## 3.2. Upravljač-Odašiljač

Početak programa nam uključuje glavnu funkciju upravljača, što je Wi-Fi interface, te

ga postavlja kao stanicu i dodaje adresu našeg robota kao odredište. Nakon što je Wi-Fi

postavljen, uključujemo pinove koje koristimo na upravljaču, to su “input” pinovi koje spajaju

naše gumbove za kretanje, pin za buzzer i gumb koji uključuje njegovo sviranje te

inicijaliziramo klasu koja upravlja sviranjem muzike.

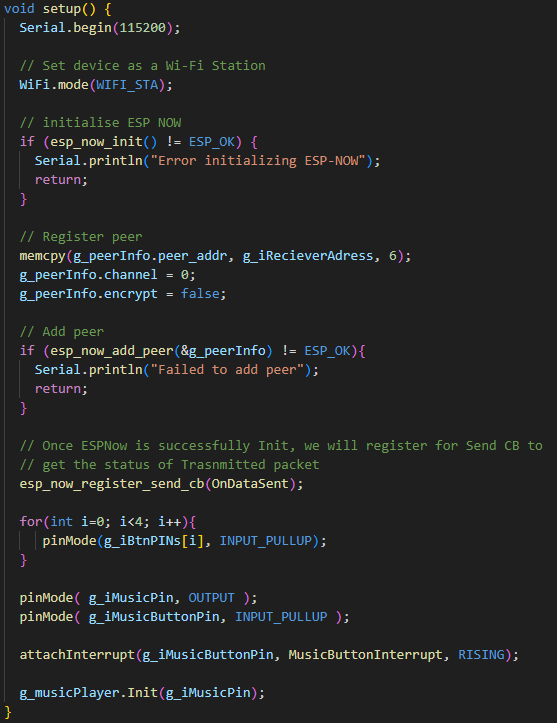
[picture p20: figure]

Loop funkcija programa ciklički učitava vrijednosti na našim gumbima, te ovisno o

njihovim vrijednostima, pošalje poruku o kretnji. Gumbi su međusobno isključivi s hijerarhijom,

što znači ako je jedan gumb pritisnut, ostali neće biti detektirani, što smanjuje količinu podataka

koju moramo poslati. Nakon što je poslana poruka, obavljamo cikličnu funkciju CMusicPlayer-

a i detektiramo ako nam je gumb za muziku bio pritisnut, u slučaju da je, počinjemo svirati

trenutnu pjesmu i postavimo sljedeću koja će se svirati.

Prije slanja svakog paketa provjerava se je li od zadnjeg poslanog paketa prošlo barem 50

milisekundi. Kada ne bi to osigurali, procesor odašiljača bi se vrlo brzo pregrijao i prestao

pravilno funkcionirati.

## 3.3. Robot-Primatelj

Početak programa uključuje naš Wi-Fi i postavlja ga kao stanicu, dodaje odašiljač kao

dio mreže, te nas postavlja kao slušatelj u mreži. Nakon postavljanja Wi-Fi-ja, uključujemo

kontroler kotača, postavljajmo lijevi i desni žmigavac, te postavljamo svirač upozorenja

kretanja unatrag.

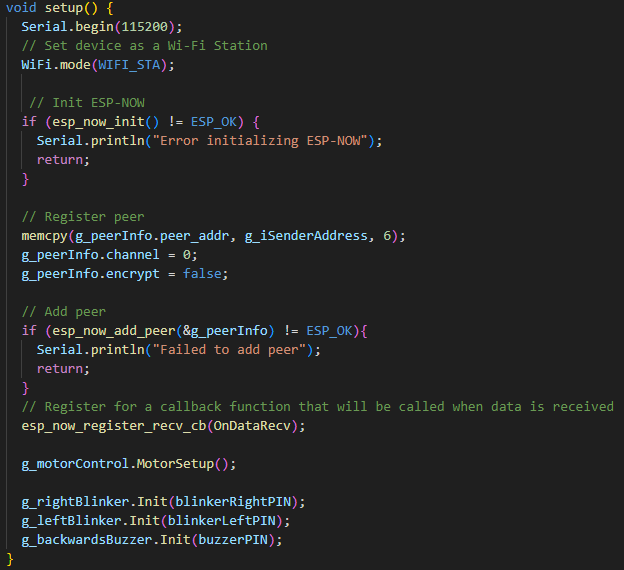
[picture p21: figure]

Na početku loop funkcije obavljamo sve potrebne ciklične funkcije naših aparata, nakon

čega učitamo komandu odašiljača i krećemo kotače u skladu s njom.

U slučaju kretanja naprijed ili nazad, provjerimo udaljenost te u slučaju da je manja od

10 centimetara, ne dozvolimo kretanje.

Ako se okrećemo lijevo ili desno, uključujemo prikladni žmigavac, te ako se krećemo

prema iza, upalimo Buzzer za upozorenje.

Na kraju provjerimo da li se trebaju žmigavci ili Buzzer ugasiti, te ih onda prikladno

ugasimo.

Primanje signala se odvija na drugoj dretvi, te koristi sljedeći callback:

## 4. Kratki troškovnik i financijska analiza

Cijena komponenti za izgradnju uključuje sve dijelove proizvoda, dijelove proizvoda koji

su bili korišteni u razvoju no nisu uključeni u finalno rješenje i alate korištene za razvoj.

Izvori cijena: [8], [9]

Dijelovi finalnog proizvoda uključuju:

- 2x Dasduino CONNECTPLUS (2 x 14€)
- 2x eksperimentalna pločica (2 x 5,5€)
- 5x tipkalo 12mm (5 x 0,4€)
- 2x kablići (2x 5€)
- Li-ion baterija 500mAh 3.7V (5,5€)
- 2x DC upravljač motora L298N (2x 6€)
- 4x kotači, 4x DC motori, 2x plastične platforme, žice, šarafi i držači (9€)
- 2x ultrazvučni modul HC-SR04 (4€)
- 3x LED lampica (3x 0,2€)
- 2x zujalica (2x 0,75€)
- 2x industrijska baterija 9V (2x 5€)
- 5x industrijska baterija AA (5x 1,5€)
- Trošak prijevoza 3,5€ po narudžbi

To ukupno daje 102,6€.

Dijelovi koji su bili korišteni u razvoju proizvoda no nisu u finalnoj arhitekturi:

- 433MHz 4-kanalni prijemnik + daljinski upravljač (5,5€)
- 2x industrijska baterija 9V (2x 5€)
- 5x industrijska baterija AA (5x 1,5€)

To ukupno daje 23€.

Alati koji su bili korišteni u razvoju proizvoda:

- Digitalni multimetar (13,5€)
- Iznajmljivanje 3D printera (5€)

To ukupno daje 18,5€.

Ukupna cijena komponenti za izgradnju jedne jedinice je 102,6€ + 23€ + 18,5€ = 142€

Kako bi izgradili više od jedne jedinice trebamo umnažati vrijednost komponenti za

sastavljanje finalnog proizvoda. Cijene bi bile:

1 proizvod 142€

2 proizvoda 246,7€

3 proizvoda 349,3€

5 proizvoda 554.5€

10 proizvoda 1067.5€

## 5. Korisnička dokumentacija

Cilj korisničke dokumentacije jest na jednostavan i razumljiv način prikazati korisniku

načine upravljanja i korištenja robota. Korisnička dokumentacija uključuje uvid u sve

funkcionalnosti robota, kao i dodatna pojašnjenja kako robot obavlja određene zadatke. Za

jednostavnije i ugodnije iskustvo rukovanja robotom potrebno je imati razumijevanje u osnovne

principe rada samog robota. Korisnička dokumentacija, također ima još jednu ulogu, a to je da

u slučaju manjeg kvara na robotu, korisnik može sam doći do zaključka koji dio robota ne radi.

Korisnik može doći do tog zaključka tako što je u korisničkoj dokumentaciji detaljno opisano

kako bi se robot trebao ponašati uslijed izvršavanja određenih naredbi. U slučaju da robot ne

izvršava radnje koje su opisane u dokumentaciji, znači da je robot u kvaru i ne radi ispravno.

Korisnička dokumentacija je nadalje podijeljena na dva dijela, kretanje robota te ostale

funkcionalnosti.

## 5.1. Kretanje robota

Upravljanje robotom se ostvaruje pomoću odašiljača, odnosno daljinskog kontrolera.

Na kontroleru je moguće uočiti Dasduino CONNECTPLUS pločicu, pet tipkala (gumba) u

raznim bojama, zujalicu te mnoštvo konekcija (žica). Bitna napomena je da se kontroler uvijek

drži u ruci u položaju kako je prikazan na slici [Slika 33], i to da se Dasduino pločica nalazi s

lijeve strane kontrolera, a crveno tipkalo (gumb) i zujalica se nalaze na desnoj strani.

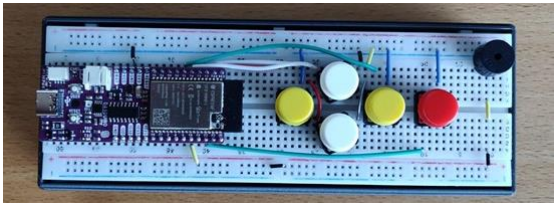
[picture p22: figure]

Slika 33: odašiljač / daljinski kontroler

Kretanje robota se postiže pritiskom na bijela ili žuta tipkala. Ovisno o položaju na

kojem se tipkala nalaze, u tom smjeru će se i robot kretati. Bijela tipkala služe za pomicanje

robota u smjeru naprijed – nazad, dok žuta tipkala služe za okretanje robota u smjeru lijevo –

desno. Kretanje je izrađeno vrlo intuitivno pa tako, gornji bijeli gumb predstavlja kretanje

unaprijed, a donji bijeli gumb predstavlja kretanje unazad. Lijevo žuto tipkalo služi za skretanje

robota u lijevo, a desno žuto tipkalo daje naredbu robotu za skretanje u desnu stranu. Kretanje robota se odvija sve dok korisnik drži pritisnut gumb. Čim korisnik ispusti gumb, robot staje s

kretanjem.

Nije moguće držati pritisnuta dva gumba (na primjer davanje naredbi za naprijed i

lijevo), već će se u tom slučaju izvoditi naredba samo onog gumba koji ima veći prioritet.

Prioriteti izvođenja operacija su definirani unutar programskog rješenja te ih nije moguće

mijenjati niti utjecati na njih. Dakle, ukratko rečeno, kretanjem robota se upravlja pritiskom na

samo jedno tipkalo odjednom. Za promjenu smjera kretanja, potrebno je ispustiti trenutno

tipkalo i stisnuti drugo tipkalo.

## 5.2. Ostale funkcionalnosti

Ostale funkcionalnosti robota, ili bolje rečeno dodatne funkcionalnosti robota, utječu na

korisničko iskustvo prilikom upravljanja robotom. U dodatne funkcionalnosti spada sustav

žmigavaca, automatskog kočenja, vožnja unazad uz upozorenje, te opcija radija.

Sustav žmigavaca se aktivira prilikom skretanja ulijevo ili udesno. Kada korisnik drži

pritisnut gumb za skretanje, robot naizmjenice pali i gasi LED diodu (lijevu ili desnu), ovisno u

koju stranu robot skreće.

Sustav automatskog kočenja je postignut ugradnjom ultrazvučnih senzora. Ultrazvučni

senzori se nalaze na prednjem i zadnjem dijelu robota te neprestano mjere udaljenost. U

slučaju ako se robot približi nekoj prepreci na udaljenosti manjoj od 10 cm, robot samostalno

koči, kako bi spriječio sudar. Ova funkcionalnost je implementirana kako bi se postigla

određena sigurnost robota, ali i sigurnost okoline u kojoj se robot kreće. Na slijedećoj slici se

može vidjeti slučaj kočenja robota koji se našao pred preprekom. [Slika 35]

Slika 34: sustav žmigavaca

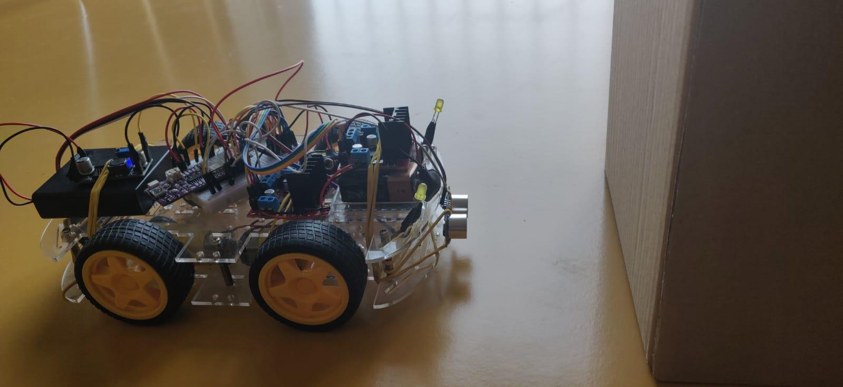
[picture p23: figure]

Automatsko kočenje nije moguće aktivirati niti deaktivirati, već je prisutno tijekom cijele

vožnje robota. Također, još je potrebno istaknuti što se događa s robotom jednom kada zakoči

i stane ispred prepreke. Recimo da je robot vozio naprijed i naišao na prepreku s prednje

strane. U tom slučaju korisnik pritiskom na gumb naprijed neće postići ništa. Robot se

jednostavno neće htjeti kretati unaprijed. Stoga, potrebno je pritisnuti gumb za unazad,

odmaknuti se od prepreke, te kada ultrazvučni senzor više ne očitava prepreku ispred sebe,

robot će se ponovno moći kretati unaprijed pritiskom na gumb naprijed. Na isti način

automatsko kočenje funkcionira kod vožnje unazad.

Vožnja unazad uz upozorenje uključuje zujalicu. Ideja ovoga je da robot pruži zvučno

upozorenje kada se kreće unazad. Prilikom kretanja unazad zujalica se oglašava u intervalima,

proizvodeći time zvučno upozorenje.

Slika 35: sustav automatskog kočenja

Slika 36: vožnja unazad uz upozorenje

Opcija radija je jedina funkcionalnost koja se ne izvršava na robotu, već na kontroleru.

Naime, ukoliko je atmosfera tijekom vožnje robota dosta monotona i dosadna, korisnik

pritiskom na crveno tipkalo na kontroleru, ima mogućnost uključivanja radija. Radio, ili bolje

rečeno zujalica, ima spremljene razne prepoznatljive melodije, koje korisnik može mijenjati

ponovnim pritiskom na isto crveno tipkalo. Ovakva funkcionalnost omogućuje ne samo

pozitivno korisničko iskustvo, već pruža korisniku osjećaj slobode i izbora.

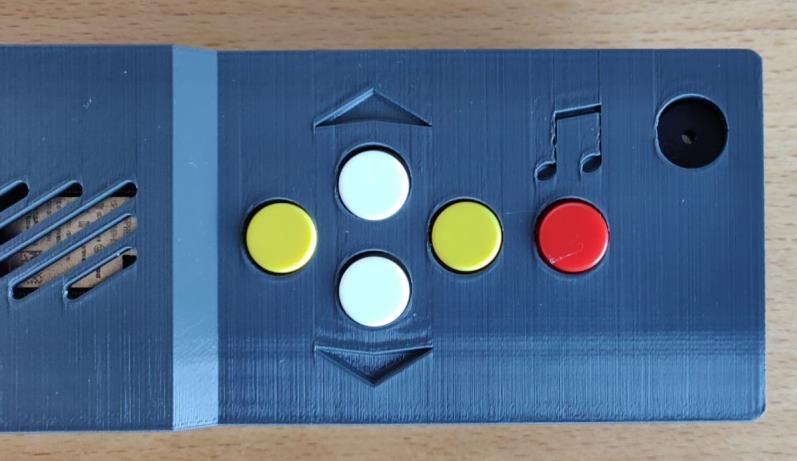
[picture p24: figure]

Slika 37: prikaz zujalice / radio na kontroleru

## 6. Zaključak

U konačnici, izrađeni robot zajedno s daljinskim kontrolerom predstavlja savršeni spoj

mehanike, elektronike i informatike. Cjelokupni sustav se temelji na Dasduino

CONNECTPLUS pločicama koje omogućuju komunikaciju između kontrolera i robota.

Korištene su različite elektroničke komponente poput upravljača motora, ultrazvučnih senzora,

zujalica i LED dioda. Ovi dijelovi su integrirani u kompleksnu arhitekturu sustava koja

omogućuje upravljanje kretanjem robota, svjetlosnim efektima i reprodukcijom zvuka. Pomoću

precizno definiranih komunikacijskih dijagrama, jasno je prikazana interakcija između

komponenti sustava u različitim situacijama, od korisničkih komandi do autonomnih aktivnosti

robota. Kroz dijagrame aktivnosti, jasno se prikazuje kako su aktivnosti koordinirane između

korisnika, upravljača i robota. Shema spajanja pruža detaljan uvid u sve komponente robota

spojene u jednu cjelinu i olakšava promatranje i razumijevanje robota kao složenog sustava.

Izvršni programi robota i kontrolera sadrže naredbe koje se neprestano odvijaju u Dasduino

pločicama, te time pružaju nesmetan rad robota. Prikaz troškovnika i financijske analize daje

uvid u cijene komponenata na tržištu, te samim time pruža i uvid u okvirnu vrijednost izrađenog

robota. Uloga korisničke dokumentacije je da korisniku olakša i pojednostavi proces

upravljanja robotom, te također objašnjava slučajeve korištenja robota i njihove ishode. Može

se reći da je korisnička dokumentacija prikaz pravilnog ponašanja robota. Naposljetku, projekt

je zahtijevao ne samo tehničke vještine u području elektronike i programiranja već i timsku

suradnju i dobru organiziranost. Uzimajući u obzir sve navedeno, možemo zaključiti da je ovaj

projekt uspješno ostvaren, pridonoseći stjecanju i razvoju novih znanja i vještina iz područja

ugrađenih sustava i programiranja.

## Popis literature

[1] robot - Hrvatska enciklopedija. (bez dat.). Pristupano 30. prosinca, 2023, sa

https://enciklopedija.hr/natuknica.aspx?ID=53100

[2] Dasduino CONNECTPLUS. (bez dat.). Pristupano 28. prosinca, 2024, sa

https://soldered.com/hr/proizvod/dasduino-connectplus/

[3] In-Depth: Interface L298N DC Motor Driver Module with Arduino. (bez dat.). Pristupano
28. prosinca, 2024, sa https://lastminuteengineers.com/l298n-dc-stepper-driver-arduino-

tutorial/?utm_content=cmp-true (https://lastminuteengineers.com/l298n-dc-stepper-driver-arduino-tutorial/?utm_content=cmp-true)

[4] HC-SR04 Ultrasonic Sensor Working, Pinout, Features & Datasheet. (bez dat.).

Pristupano 28. prosinca, 2024, sa https://components101.com/sensors/ultrasonic-sensor-

working-pinout-datasheet (https://components101.com/sensors/ultrasonic-sensor-working-pinout-datasheet)

[5] „How to Draw UML Communication Diagram?“ Pristupljeno: 13. siječanj 2024. [Na internetu]. Dostupno na: https://www.visual-paradigm.com/tutorials/how-to-draw-

communication-diagram.jsp (https://www.visual-paradigm.com/tutorials/how-to-draw-communication-diagram.jsp)

[6] „ESP32 Dual Core with Arduino IDE | Random Nerd Tutorials“. Pristupljeno: 13. siječanj
2024. [Na internetu]. Dostupno na: https://randomnerdtutorials.com/esp32-dual-core-

arduino-ide/ (https://randomnerdtutorials.com/esp32-dual-core-arduino-ide/)

[7] „What is Activity Diagram?“ Pristupljeno: 13. siječanj 2024. [Na internetu . Dostupno na: https://www.visual-paradigm.com/guide/uml-unified-modeling-language/what-is-

activity-diagram/ (https://www.visual-paradigm.com/guide/uml-unified-modeling-language/what-is-activity-diagram/)

[8 „Homepage“, Soldered Electronics. Pristupljeno: 13. siječanj 2024. [Na internetu . Dostupno na: https://soldered.com/

[9 „Amazon.com. Spend less. Smile more.“ Pristupljeno: 13. siječanj 2024. [Na internetu . Dostupno na: https://www.amazon.com/

[10] GitHub – robsoncouto/arduino-songs Pristupljeno: 14. siječanj 2024. [Na internetu].

Dostupno na: https://github.com/robsoncouto/arduino-songs

## Popis slika

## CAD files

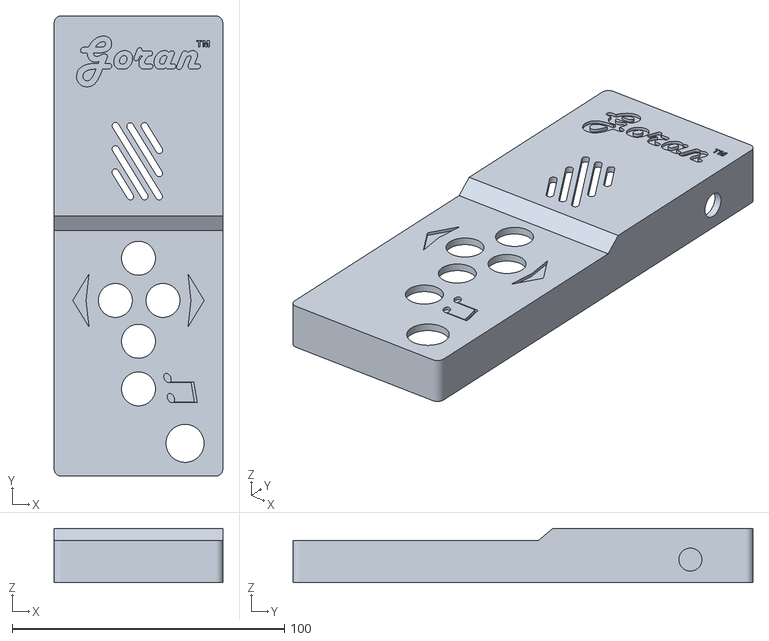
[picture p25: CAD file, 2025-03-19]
3D-modeli/Odasiljac-maska-gornji-dio.stl
62.0 x 169.0 x 20.0

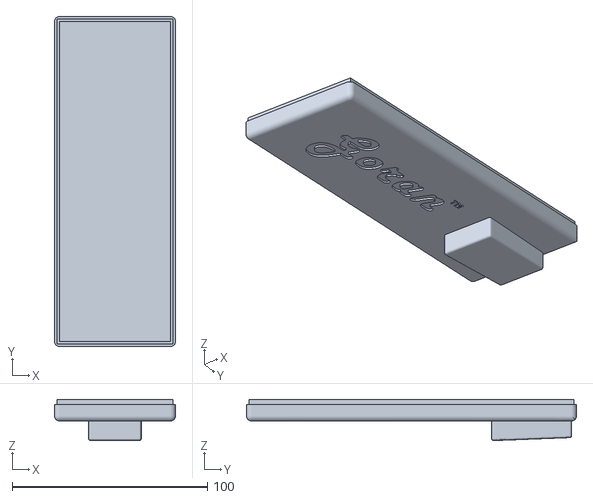
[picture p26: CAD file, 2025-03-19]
3D-modeli/Odasiljac-maska-donji-dio.stl
62.0 x 169.0 x 21.0

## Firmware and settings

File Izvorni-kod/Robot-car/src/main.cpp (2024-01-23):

//#define SHOW_DEBUG_MESSAGES

#include <Arduino.h>
#include <WiFi.h>
#include <esp_now.h>

#include "motor_control.h"
#include "ultrasonic_control.h"

#include "music_player.h"
#include "songs.h"
#include "blinker.h"

const int blinkerLeftPIN = 13;
const int blinkerRightPIN = 12;
const int buzzerPIN = 18;

const int ultrasonicBackRecievePIN = 5;
const int ultrasonicBackSendPIN = 15;
const int ultrasonicFrontRecievePIN = 4;
const int ultrasonicFrontSendPIN = 14;

// defining motor control pins
unsigned int motorInputPIN1 = 21;
unsigned int motorInputPIN2 = 22;
unsigned int motorInputPIN3 = 23;
unsigned int motorInputPIN4 = 19;

// -- ESP NOW --
uint8_t g_iSenderAddress[] = {0x7C, 0x87, 0xCE, 0xF8, 0xCA, 0xE8};

int g_iCommand = 0; // values of recieved message
// UP, DOWN, LEFT, RIGHT

typedef struct struct_message { // structure of receiving message
    int m_iCommand;
} struct_message;

struct_message g_incomingCode;

esp_now_peer_info_t g_peerInfo;

// Callback when data is received
void OnDataRecv(const uint8_t * mac, const uint8_t *incomingData, int len);
// -- ESP NOW --

CUltrasonicControl g_ultrasonicControlBack(ultrasonicBackRecievePIN, ultrasonicBackSendPIN);
CUltrasonicControl g_ultrasonicControlForward(ultrasonicFrontRecievePIN, ultrasonicFrontSendPIN);

CBlinker g_rightBlinker;
CBlinker g_leftBlinker;
CMusicPlayer g_backwardsBuzzer;

CMotorControl g_motorControl(motorInputPIN1,motorInputPIN2,motorInputPIN3,motorInputPIN4);

void setup() {
  Serial.begin(115200);
  // Set device as a Wi-Fi Station
  WiFi.mode(WIFI_STA);

   // Init ESP-NOW
  if (esp_now_init() != ESP_OK) {
    Serial.println("Error initializing ESP-NOW");
    return;
  }

  // Register peer
  memcpy(g_peerInfo.peer_addr, g_iSenderAddress, 6);
  g_peerInfo.channel = 0;  
  g_peerInfo.encrypt = false;
  
  // Add peer        
  if (esp_now_add_peer(&g_peerInfo) != ESP_OK){
    Serial.println("Failed to add peer");
    return;
  }
  // Register for a callback function that will be called when data is received
  esp_now_register_recv_cb(OnDataRecv);

  g_motorControl.MotorSetup();

  g_rightBlinker.Init(blinkerRightPIN);
  g_leftBlinker.Init(blinkerLeftPIN);
  g_backwardsBuzzer.Init(buzzerPIN);
}

enum MOVE_DIRECTION
{
  STOP = 0,
  FORWARDS,
  BACKWARDS,
  RIGHT,
  LEFT,
};

void loop() {
  g_ultrasonicControlForward.Think();
  g_ultrasonicControlBack.Think();
  g_rightBlinker.Think();
  g_leftBlinker.Think();
  g_backwardsBuzzer.Think();

  switch( g_iCommand ) {
    case STOP:
      g_motorControl.Stop();
      break;

    case FORWARDS:
      if( g_ultrasonicControlForward.GetCM() < 30 ) {
        g_motorControl.Stop();
        break;
      }
      g_motorControl.DriveForward();
      break;

    case BACKWARDS:
      if( g_ultrasonicControlBack.GetCM() < 30 ) {
        g_motorControl.Stop();
        break;
      }

      if( !g_backwardsBuzzer.IsPlaying() )
        g_backwardsBuzzer.StartPlayback(parking, sizeof(parking), 66);

      g_motorControl.DriveBackward();
      break;

    case RIGHT:
      if( !g_rightBlinker.IsBlinking() )
        g_rightBlinker.StartPlayback(led_blink_back, sizeof(led_blink_back), 1, true);

      g_motorControl.TurnRight();
      break;

    case LEFT:
      if( !g_leftBlinker.IsBlinking() )
        g_leftBlinker.StartPlayback(led_blink_back, sizeof(led_blink_back), 1, true);

      g_motorControl.TurnLeft();
      break;
  }

  if( g_iCommand != LEFT && g_iCommand != RIGHT ) {
    g_leftBlinker.Stop();
    g_rightBlinker.Stop();
  }

  if( g_backwardsBuzzer.IsPlaying() && g_iCommand != BACKWARDS )
    g_backwardsBuzzer.Stop();
}

void OnDataRecv(const uint8_t *mac, const uint8_t *incomingData, int len) {
  memcpy(&g_incomingCode, incomingData, sizeof(g_incomingCode)); // incomingData is the data that has been sent from the transmitter
  // incomingCode is the structure that matches the data structure of the transmitted message

  g_iCommand = g_incomingCode.m_iCommand; // alter te value of variables
}

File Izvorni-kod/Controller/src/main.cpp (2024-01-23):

#include <Arduino.h>
#include <WiFi.h>
#include <esp_now.h>
#include <music_player.h>
#include <songs.h>

const int g_iBtnPINs[] = {14, 13, 12, 15}; // UP, DOWN, LEFT, RIGHT
const int g_iMusicPin = 18;
const int g_iMusicButtonPin = 23;

// ESP NOW
const uint8_t g_iRecieverAdress[] = {0x94, 0xE6, 0x86, 0xA8, 0x61, 0x24};
esp_now_peer_info_t g_peerInfo; // information about the peer

int g_iBtnPinValues[4] = {0, 0, 0, 0}; // values in btnPINs
// this variable's value is sent to the reciever
// the values instruct the robotCar on its next action

typedef struct struct_message {
    int m_iCommand; // this variable's value is sent to the reciever
} struct_message;

struct_message g_messageToSend;
// ESP NOW

void OnDataSent(const uint8_t *mac_addr, esp_now_send_status_t status) {
  Serial.println(status == ESP_NOW_SEND_SUCCESS ? "Delivery Success" : "Delivery Fail");
}

unsigned long g_flLastSentTime = 0;

CMusicPlayer g_musicPlayer;

bool g_bMusicButtonPressed = false;

volatile bool g_bButtonPressed = false;
unsigned long g_flLastInterruptTime = 0;

void IRAM_ATTR MusicButtonInterrupt()
{
  if( millis() - g_flLastInterruptTime > 200 ) {
    g_bMusicButtonPressed = true;
    g_flLastInterruptTime = millis();
  }
}


int g_iCurrentSong = 0;
#define g_iSongCount 4

const int *g_szSongs[g_iSongCount] =
{
  tetris,
  keyboardcat,
  vader,
  takeonme
};

size_t g_iSongSize[g_iSongCount] = 
{
  sizeof(tetris),
  sizeof(keyboardcat),
  sizeof(vader),
  sizeof(takeonme)
};

const int g_iSongTempos[g_iSongCount] = 
{
  144,
  160,
  120,
  140
};


void setup() {
  Serial.begin(115200);
  
  // Set device as a Wi-Fi Station
  WiFi.mode(WIFI_STA);
  
  // initialise ESP NOW
  if (esp_now_init() != ESP_OK) {
    Serial.println("Error initializing ESP-NOW");
    return;
  }

  // Register peer
  memcpy(g_peerInfo.peer_addr, g_iRecieverAdress, 6);
  g_peerInfo.channel = 0;
  g_peerInfo.encrypt = false;

  // Add peer
  if (esp_now_add_peer(&g_peerInfo) != ESP_OK){
    Serial.println("Failed to add peer");
    return;
  }

  // Once ESPNow is successfully Init, we will register for Send CB to
  // get the status of Trasnmitted packet
  esp_now_register_send_cb(OnDataSent);

  for(int i=0; i<4; i++){
     pinMode(g_iBtnPINs[i], INPUT_PULLUP); 
  }
  
  pinMode( g_iMusicPin, OUTPUT );
  pinMode( g_iMusicButtonPin, INPUT_PULLUP );

  attachInterrupt(g_iMusicButtonPin, MusicButtonInterrupt, RISING);

  g_musicPlayer.Init(g_iMusicPin);
}

void loop() {

  if(!digitalRead(g_iBtnPINs[3])){ // if RIGHT
    g_messageToSend.m_iCommand = 4;
  } else if(!digitalRead(g_iBtnPINs[2])){ // if LEFT
    g_messageToSend.m_iCommand = 3;
  }else if(!digitalRead(g_iBtnPINs[1])){ // if DOWN
    g_messageToSend.m_iCommand = 2;
  }else if(!digitalRead(g_iBtnPINs[0])){ // if UP
    g_messageToSend.m_iCommand = 1;
  }else{
    g_messageToSend.m_iCommand = 0;
  }

  //Serial.println(messageToSend.command);

  //ESP NOW send the message and get the result
  if( millis() - g_flLastSentTime > 50 ){
    //Serial.println("sending " + g_messageToSend.m_iCommand);
    g_flLastSentTime = millis();

    esp_err_t result = esp_now_send(g_iRecieverAdress, (uint8_t *) &g_messageToSend, sizeof(g_messageToSend));
  }
  

  g_musicPlayer.Think();

  if( g_bMusicButtonPressed ) {
      g_musicPlayer.StartPlayback(g_szSongs[g_iCurrentSong], g_iSongSize[g_iCurrentSong], g_iSongTempos[g_iCurrentSong]);

      g_iCurrentSong++;

      if( g_iCurrentSong >= g_iSongCount )
        g_iCurrentSong = 0;

      g_bMusicButtonPressed = false;
  }
}

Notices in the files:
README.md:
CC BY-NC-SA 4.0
